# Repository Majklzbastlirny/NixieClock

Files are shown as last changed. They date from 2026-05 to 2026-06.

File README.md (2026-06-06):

# NixieClock (ESP-IDF firmware)

ESP-IDF + PlatformIO firmware for a 6-tube multiplexed nixie clock, replacing
the original ESPHome config (`nixieclock.yaml`, kept for reference). WiFi is used
for time sync and remote control; the clock keeps running (and keeps time, via
its RTC) with no network.

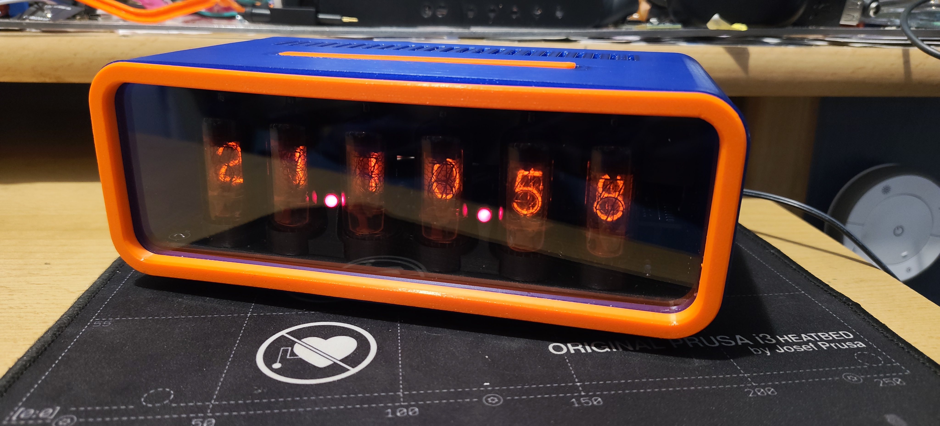
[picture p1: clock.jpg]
The clock


> **New here?** See **[GUIDE.md](GUIDE.md)** — a bilingual (English / Čeština)
> user guide with a *For everyone* section (setup, buttons, web page) and a
> *Power users* section (REST, MQTT/Home Assistant, building the firmware).

## Hardware

ESP32 (WROOM-32) on the **UCB32** controller board driving the
[**Unidisp**](https://github.com/Unipuls80/Unidisp) display board:

- Onboard UC3845 HV supply (~180 V, **no dimming input** → brightness is done in
  firmware by PWM-ing each tube's anode within its multiplex slot — the headline
  feature that wasn't possible under ESPHome).
- **MH74141** BCD cathode driver (old/slow Tesla part), **74×42** 1-of-10 anode
  multiplexer, 6× Z57xM/ZM1080 tubes. No per-digit decimal points — the only
  separator is the colon between the MM:SS pair.
- **PCF8563** RTC @ I²C 0x51 (driver also auto-detects DS1307/DS3231 @ 0x68).
- 5 front buttons on the multiplexed KEY line + a dedicated snooze button.
- Passive piezo buzzer on the ALM line (LEDC tone / RTTTL).
- Up to 2× **DS18B20** 1-Wire temperature sensors on GPIO13 (needs a 4.7 kΩ
  pull-up to 3.3 V).

Full pin map: [`components/common/include/pins.h`](components/common/include/pins.h).
Printable enclosure (case, bezel, panels, TPU feet) + print/assembly notes:
[`3D_Files/`](3D_Files/).

## Build & flash

Requires [PlatformIO](https://platformio.org/install) (CLI or the VS Code ext).

```sh
pio run                 # build
pio run -t upload       # build + flash over USB
pio device monitor      # serial console @ 115200
```

PlatformIO downloads the ESP-IDF 5.5 toolchain and the managed components
(`espressif/onewire_bus`, `espressif/ds18b20`) automatically on first build.
After changing a component's `idf_component.yml` or `REQUIRES`, do a clean
configure (`rm -rf .pio/build/esp32dev`) so the component manager re-runs.

> The board has **no auto-reset**: hold IO0, tap EN, release IO0 to enter
> download mode before `pio run -t upload`.

## First-time setup / credentials

Credentials live in NVS (set via the SoftAP portal or the web UI).
`components/common/include/secrets.h` (gitignored) is a **first-boot fallback
only**: once a WiFi SSID is stored in NVS the device trusts NVS exclusively (an
empty MQTT host means *no MQTT* — the client goes idle), and a factory reset
forces SoftAP setup on the next boot regardless of `secrets.h`.

To seed defaults at compile time, copy the template:

```sh
cp components/common/include/secrets.example.h components/common/include/secrets.h
# edit WIFI_SSID / WIFI_PASS / MQTT_* 
```

Or skip `secrets.h` entirely and provision over WiFi (see below).

## WiFi provisioning (SoftAP)

To set credentials without editing code (e.g. when lending the clock):

1. **Enter provisioning** — hold the provision button (button 5) during the
   boot window, or long-hold it (~3 s) during normal operation; it reboots into
   setup mode. (A board with no stored creds and no fallback SSID enters it
   automatically.)
2. The tubes show an **8-digit PIN** in two halves (colon lit = first half).
   Join the open-looking `NixieClock-XXXXXX` WiFi using that PIN as the WPA2
   password — so only someone looking at the clock can connect.
3. A captive portal opens: pick your network, enter the password (and optionally
   MQTT settings), save. The clock stores the creds and reboots onto your LAN.

WiFi/MQTT can also be changed live from the web UI's **Network** section (MQTT
applies immediately; WiFi on next reboot).

## Buttons

| Button | Short press | Long hold |
|---|---|---|
| 1 | Brightness up | — |
| 2 | Brightness down | — |
| 3 | Show temperature now | — |
| 4 | Anti-poison scrub now | — |
| 5 (provision) | Show IP address on tubes | ~3 s: provisioning · ~10 s: factory reset |
| Snooze | Snooze ringing alarm | Dismiss alarm (until tomorrow) |

Bonus combo: **hold brightness + and − together (~2 s)** toggles the alarm on/off.

## Control surfaces

All three share one settings store, so changes from any surface are reflected
everywhere instantly:

- **Web UI** — `http://<clock-ip>/` : brightness, night schedule, anti-poison,
  alarm (incl. day-of-week + melody + snooze), temperature slots/decimals, and
  network config. Tap button 5 to see the IP on the tubes.
- **MQTT + Home Assistant** — auto-discovers as a *Nixie Clock* device
  (`nixie-<mac>`). Topics under `nixieclock/<node>/…`, HA discovery under
  `homeassistant/…`.
- **REST/JSON** — `GET /api/state`, `POST /api/set?k=<key>` (value in body),
  `POST /api/action?a=<action>`, `GET /api/net`, `POST /api/netset`.

## Features

- Smooth multiplex PWM brightness, ghost-free (cathode-before-anode + dead-time).
- SNTP timekeeping (Europe/Prague), seeded from and written back to the RTC.
- Manual brightness + night dimming (default 20:30→06:00); hook for a future
  BH1750 light sensor.
- Anti-cathode-poisoning cycle (periodic + on-demand).
- Two temperature slots shown near the end of each minute (sec 52–55), each fed
  by MQTT or a DS18B20; configurable decimals; negatives shown by blinking
  (no minus glyph), colon used as the decimal point.
- Alarm with snooze + dismiss, day-of-week mask, and RTTTL melodies.
- Cold-start "slot machine" animation until the time is known.

## Project layout

```
platformio.ini             build config (env: esp32dev), custom partition table
partitions.csv             single ~2.8 MB app + NVS + SPIFFS (4 MB flash)
sdkconfig.defaults         ESP-IDF defaults
src/main.c                 app entry: orchestration + display draw loop
components/
  common/                  shared pin map + secrets (header-only)
  nixie/                   GPTimer multiplex display driver + PWM brightness
  i2cbus/                  shared I²C master + bus scanner
  rtcdev/                  RTC driver (PCF8563 / DS1307 / DS3231 auto-detect)
  netclock/                WiFi STA + SNTP
  netcfg/                  WiFi/MQTT credential store (NVS + secrets fallback)
  provision/               SoftAP captive-portal WiFi provisioning
  settings/                persisted settings blob (NVS) + change versioning
  control/                 shared key=value apply + state-JSON core
  mqttctrl/                MQTT client + Home Assistant autodiscovery
  webui/                   self-hosted web UI + REST/JSON API
  temps/                   temperature slots + DS18B20 (RMT 1-Wire)
  buttons/                 multiplexed-button debounce + classification
  alarm/                   alarm state machine
  buzzer/                  LEDC tone + RTTTL player
  antipoison/              anti-cathode-poisoning routine
```

Architecture note: `control` is the single place that maps a setting key=value
and renders the state JSON; MQTT, the web UI, and REST all go through it, so
adding a setting touches one switch and one JSON builder, not three.

## License

This project uses reciprocal ("share-alike") open licenses — you may use, copy,
and modify it, including commercially, but you must publish your modifications to
whichever part you change:

- **Firmware / source code** — [GNU GPL v3](LICENSE) (`LICENSE` at the repo root).
- **UCB32 controller board** (`PCB_Sources/ucb vibecheck_final/`) —
  [CERN-OHL-S v2](PCB_Sources/ucb%20vibecheck_final/LICENSE.txt) (CERN Open
  Hardware Licence, Strongly Reciprocal).

Third-party content keeps its own license: the **Unidisp** display board
(`PCB_Sources/Unidisp-main/`) is licensed by its author under CERN-OHL-W (Weakly
Reciprocal) — see its bundled `LICENSE`. The original ESPHome reference
(`nixieclock.yaml`) is retained only for reference.

## Credits

This started as a university project. The **Unidisp** digitron display board —
the HV supply, multiplexing, and tube driving — is the work of
[**@Unipuls80**](https://github.com/Unipuls80), along with his original
[Unidisp](https://github.com/Unipuls80/Unidisp) and an
[MH106 ASIC-based controller (ucb106)](https://github.com/Unipuls80/ucb106).

The **UCB32** controller board and this ESP32 firmware are my "modern" take on
driving the same display — by **Michal Basler** ([@Majklzbastlirny](https://github.com/Majklzbastlirny)).

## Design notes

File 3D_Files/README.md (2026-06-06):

# 3D-printed enclosure

Printable parts for the clock case. All files are `.3mf`. Print the rigid parts
in **PETG** (chosen mainly because the 7805 regulator runs hot, and PETG handles
the heat better than PLA); print the feet in **TPU**.

| Preview | Part | File | Qty | Supports | Notes |
|---|---|---|-----|---|---|
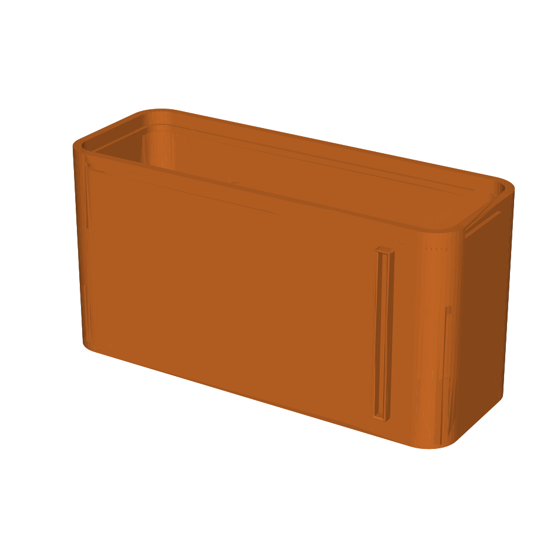
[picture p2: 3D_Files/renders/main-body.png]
|  | Main body / shell | [`main-body.3mf`](main-body.3mf) | 1 | **Yes** | The enclosure everything mounts inside. Takes 2× M3 heat-set inserts (see *Hardware*). |
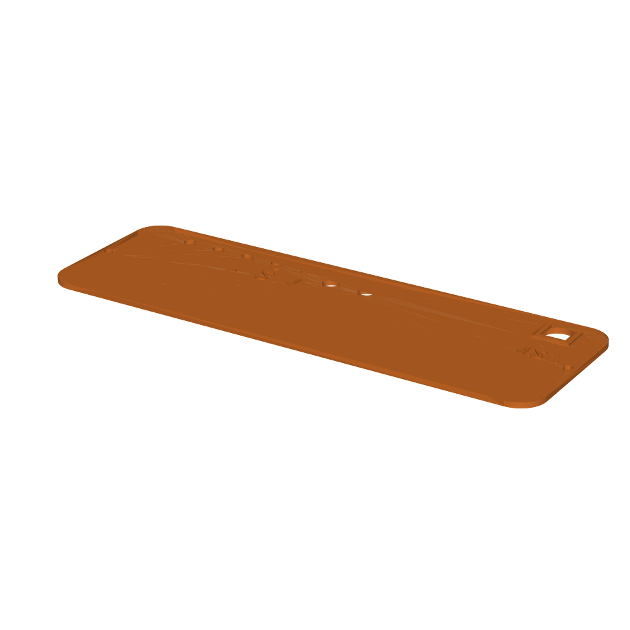
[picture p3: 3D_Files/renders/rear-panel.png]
|  | Rear panel | [`rear-panel.3mf`](rear-panel.3mf) | 1 | No | MMU / multi-color: printed labels for each rear button, the temperature-probe jacks, and the barrel-jack voltage. Screws onto the main body. |
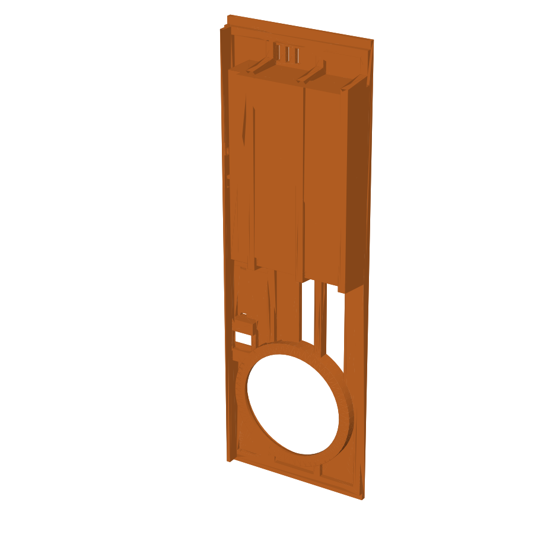
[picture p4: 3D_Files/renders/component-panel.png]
|  | Component panel | [`component-panel.3mf`](component-panel.3mf) | 1 | **Yes** | Internal bracket that holds the accessory hardware: alarm speaker, RTC coin-cell holder, and the snooze button. |
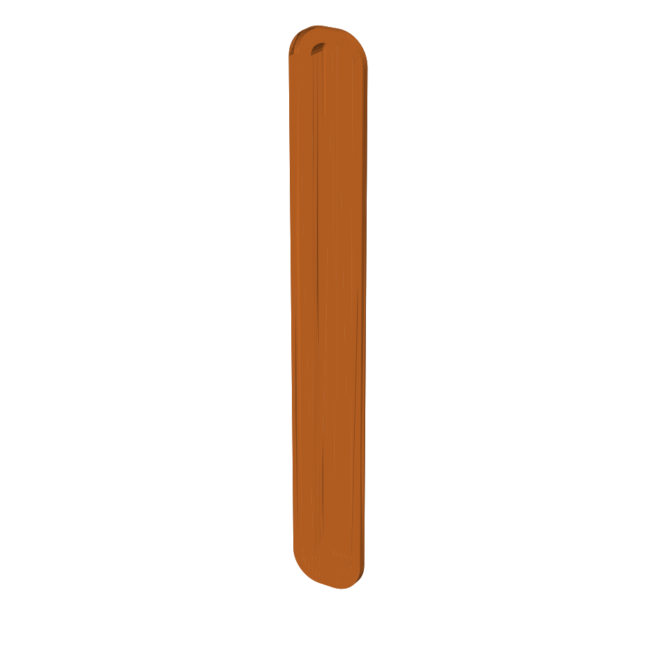
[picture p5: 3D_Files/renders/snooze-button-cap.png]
|  | Snooze button cap | [`snooze-button-cap.3mf`](snooze-button-cap.3mf) | 1 | No | One printed rocker cap; the two physical tact switches sit under its edges. Mounts in the component panel. |
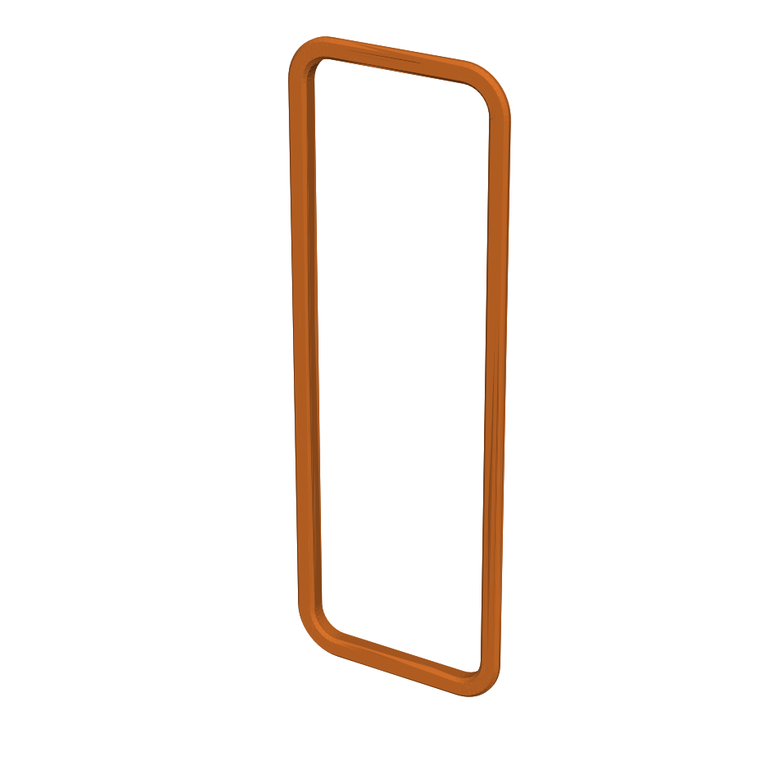
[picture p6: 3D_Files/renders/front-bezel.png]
|  | Front bezel | [`front-bezel.3mf`](front-bezel.3mf) | 1 | No | Hides the rough-cut front plexiglass edge. **Scale to 98 %** to fit as-is — or shave the lip if you print at 100 %. |
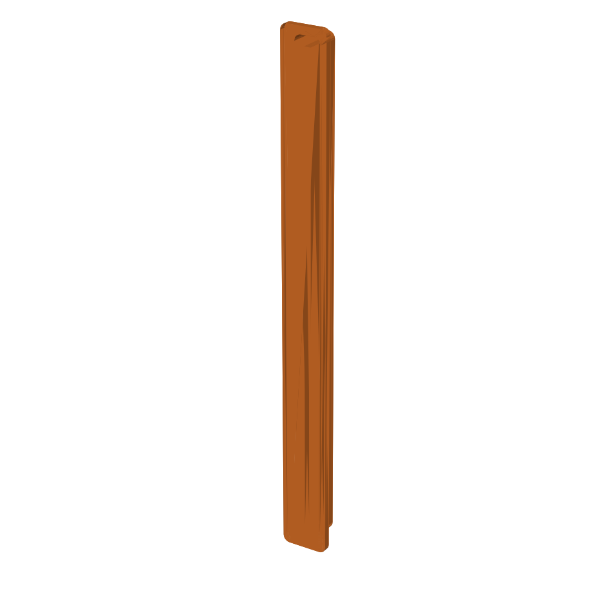
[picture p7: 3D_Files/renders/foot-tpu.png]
|  | Foot | [`foot-tpu.3mf`](foot-tpu.3mf) | 2 | No | Print in **TPU** (flexible). |

> Preview images in `renders/` are auto-generated from the `.3mf` files by
> [`_render.py`](_render.py) (a throwaway matplotlib/trimesh helper).

## Hardware (case assembly)

- **2× M3 heat-set threaded inserts** — installed in the main body.
- **2× M3×4 screws** — fasten the rear panel into those inserts.

(Electronics/wiring hardware is covered in the main project docs.)

## Print tips

- Everything rigid is **PETG** — the 7805 linear regulator dumps a fair bit of
  heat, so PLA isn't ideal near it.
- The main body and component panel use supports; orient so the support contact
  stays off visible faces.
- The rear panel is set up for a multi-material (MMU) printer so the labels come
  out in a contrasting color; on a single-material printer it still prints fine,
  the markings just won't be color-separated.
- Front bezel: if it's tight, the 98 % scale is the easy fix; the alternative is
  trimming the locating lip.

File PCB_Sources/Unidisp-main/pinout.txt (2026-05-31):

P.V.B. @ Crazy Electronics   13/02/23

------X1------
		
		Konektor pro připojení napájení. (+) je připojeno ke středovému trnu.

------X2------

S0/LSB		Paralelní vstup multiplexování. Hodnotě 0 odpovídá digitron úplně vpravo,
S1		hodnotě 5 odpovídá digitron úplně vlevo, hodnoty 6 a výše zhasínají displej
S2/MSB

D0/LSB		Paralelní vstup zobrazené číslice, formát BCD
D1
D2
D3/MSB

------X3------

KEY		Výstup tlačítek. Tlačítka jsou multiplexovaná, aktivní úroveň L posutá o jeden úbytek diody na 0,6V. 
		Tlačítka jsou multiplexovaná společně s digitrony: 
		S1:LLH, S2:HHL, S3:LHL, S4:HLL, S5:LLL (S0, S1, S2)

ALM:		Ovládání budiče pro akustický měnič budíku. 

DP:		Řízení desetinných teček. Úroveň H otevírá tranzistor, spínající katodu navolenou pájecími
		body JP1, JP2. Tečky jsou rovněž multiplexované.

COL:		Řízení spínače oddělovačů. Oddělovači se rozumí dvojtečky mezi páry digitronů - 12:34:56.

P5V:		Rozvod 5V pro napájení nadřazených obvodů. Bez přídavného chladiče na A1 doporučuji odebírat max 200mA.

GND:		Rozvod nuly. (GND)

P12V:		Rozvod nestabilizovaného napájení. Napětí odpovídá napětí dodávaného z externího napáječe přes X1.

-----X4,5-----

		Připojení LED diod oddělovačů. Oddělovače jsou tvořeny dvěma LED připojenými ke konektorům X4, X5. 
		Anody jsou spojené do vývodu 2, katody na vývodech 1, 3 X4, respektive X5.

-----X6,7-----

		Připojení akustického měniče, budič je navržen především pro buzení pasivního piezo měniče.
		Umožňuje i buzení reproduktorku přes vazební kondenzátor. Výstup je na X6, X7 je 0V.

Všechny log. I/O jsou úrovní TTL 5V.

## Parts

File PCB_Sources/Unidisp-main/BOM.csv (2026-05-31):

Indukčnosti
L1 | 100uH 2A pp. 50kHz | radiální
Rezistory
R1 | CdS 5mm | -
R2, R45 | 47k 5% | R0207
R3 | 150k 5% | R0207
R4 | 10k 1% | R0207
R5, R47 | 47R 5% | R0207
R6 | 2k2 5% | R0207
R7, R8 | 2R2 5% | R0207
R9 | 390k 1% | R0207
R10 | 100k 1% | R0207
R11 | 6k8 1% | R0207
R12 .. R23 | 22k 5% | R0207
R30 .. R35
R24 .. R29 | 330k 5% | R0207
R36 | 1k 5% | R0207
R37, R38 | 10k 5% | R0207
R43, R44
R39 .. R42, R46 | 560R 5% | R0207
Kondenzátory
C1 | 470uF 16V | elektrol. radiální
C2, C3, C9 | 100n 16V | keramický
C10, C11
C4 | 100p 16V | keramický
C5 | 10n 16V | keramický
C6 | 1n5 16V | keramický
C7 | 2n2 16V | keramický
C8 | 4,7uF 250V | elektrol. radiální
Diody
V1 | 1N4007 | -
V2 | UF4007 | -
V3..V7 | 1N4148 | -
Tranzistory
VT1 | IRF740 | upevnit k DPS
VT2..VT7 | MPSA92 | -
VT8..VT13, VT15 | MPSA42 | -
VT14, VT16 | BC547 | -
VT17 | BC556 | -
Integrované obvody
A1 | MA7805 | upevnit k DPS
A2 | UC3845 | -
D1 | 74x42 | -
D2 | 74x141 | -
Výbojky
E1..E6 | Z57xM, ZM1080(T) a ekvivalentní
Konektory
X1 | zdířka souosá | 5,5mm/2,1mm
X2..X7 | hřeben, samec | 2,54mm
Pojistky
F1 | podle celk. odběru | 5x20mm
pouzdro pro F1 | PTF76 | 15mm rozteč

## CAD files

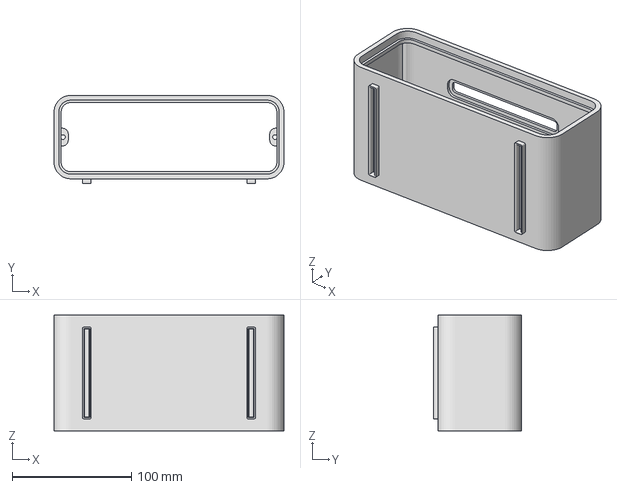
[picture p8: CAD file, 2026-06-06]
3D_Files/main-body.3mf
193.0 x 74.0 x 97.0 mm

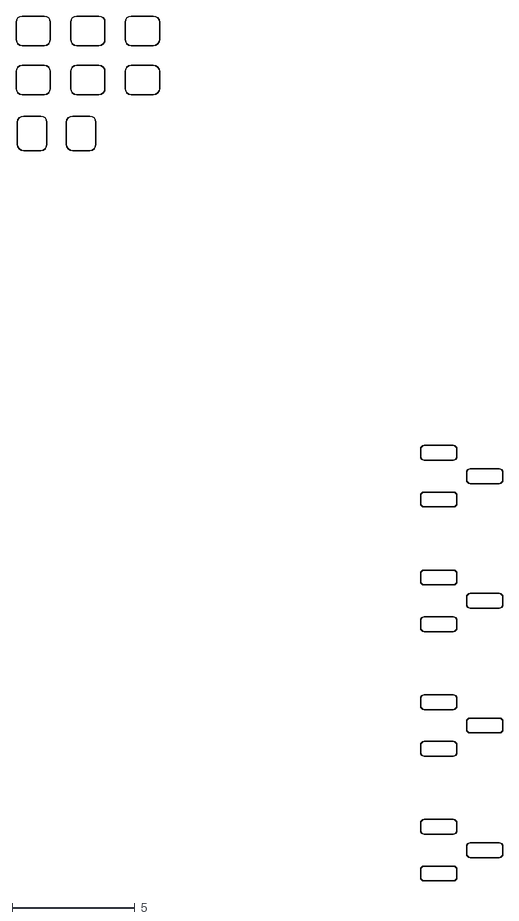
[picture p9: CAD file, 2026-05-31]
PCB_Sources/ucb vibecheck_final/UCB32-PasteBottom.dxf
19.8 x 35.2

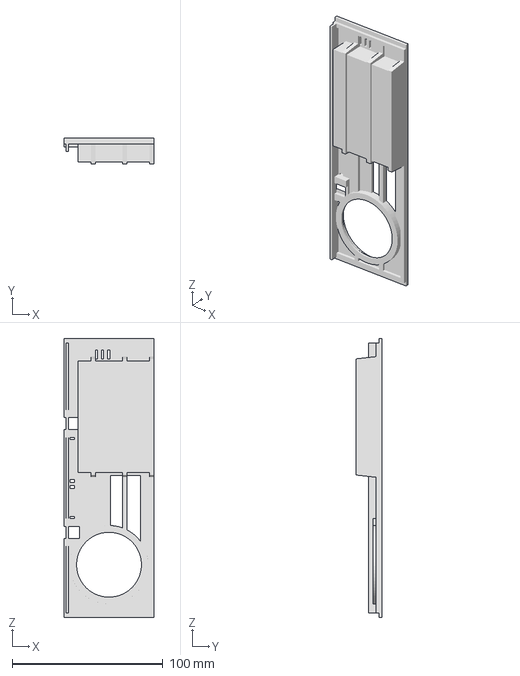
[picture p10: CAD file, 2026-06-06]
3D_Files/component-panel.3mf
60.0 x 17.5 x 185.0 mm

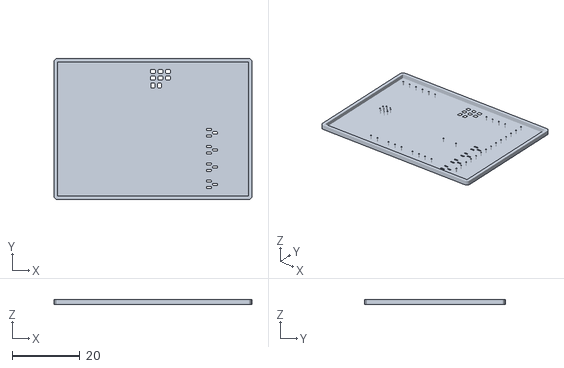
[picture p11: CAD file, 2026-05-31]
PCB_Sources/ucb vibecheck_final/bottomStencil.stl
58.5 x 41.7 x 1.45

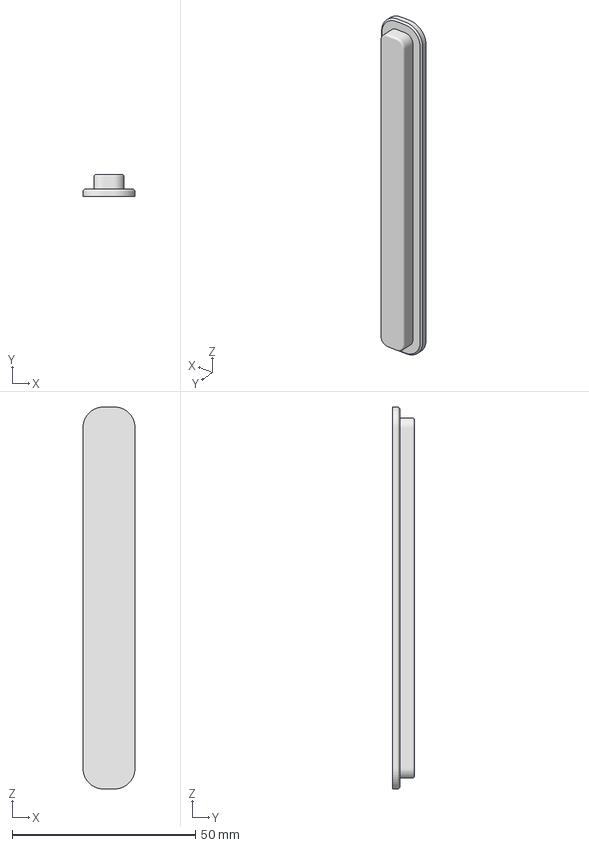
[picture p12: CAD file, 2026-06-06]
3D_Files/snooze-button-cap.3mf
14.2 x 6.00 x 104.2 mm

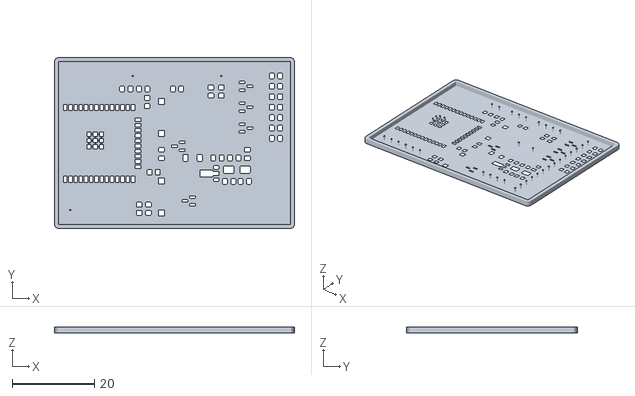
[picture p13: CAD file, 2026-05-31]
PCB_Sources/ucb vibecheck_final/topStencil.stl
58.5 x 41.7 x 1.45

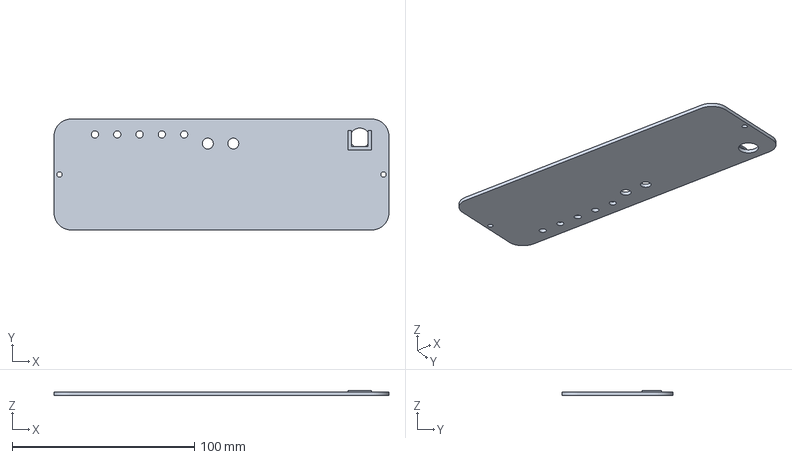
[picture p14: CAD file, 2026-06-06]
3D_Files/rear-panel.3mf
184.0 x 61.0 x 3.00 mm

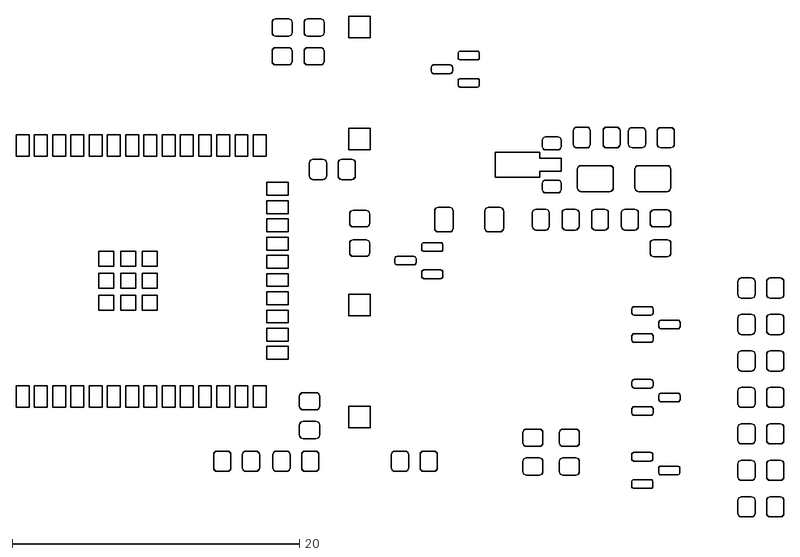
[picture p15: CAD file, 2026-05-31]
PCB_Sources/ucb vibecheck_final/UCB32-PasteTop.dxf
53.5 x 34.9

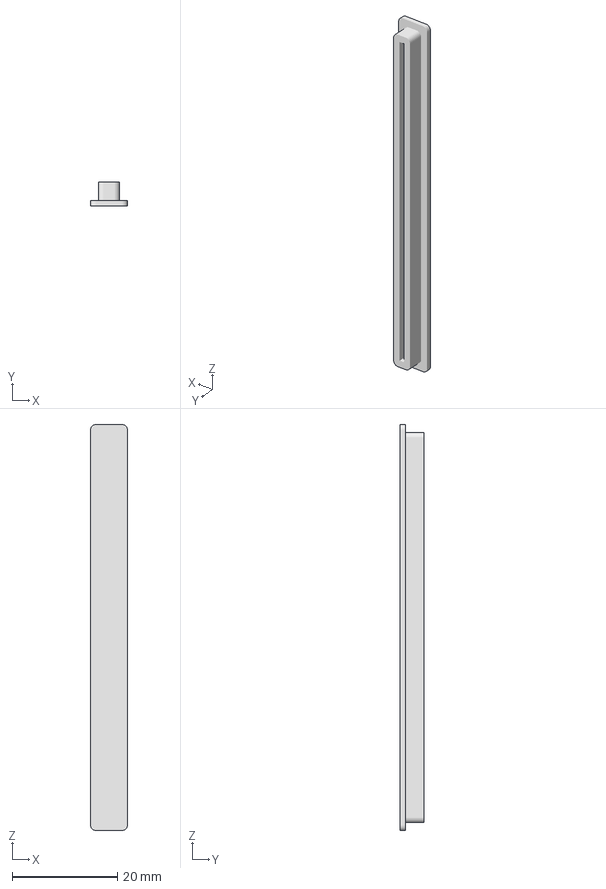
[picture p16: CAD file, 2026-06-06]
3D_Files/foot-tpu.3mf
7.00 x 4.50 x 77.0 mm

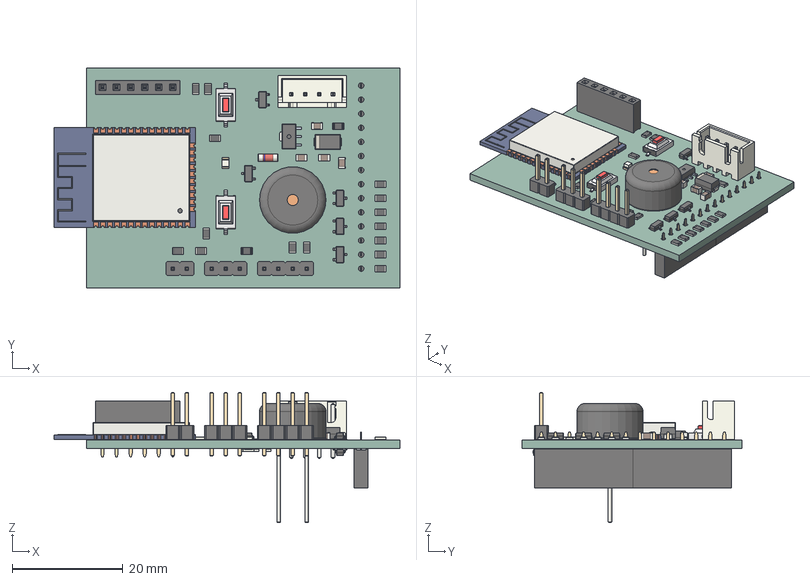
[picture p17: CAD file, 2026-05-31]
PCB_Sources/ucb vibecheck_final/UCB32.step
62.4 x 39.7 x 23.5 mm
R_0805_2012Metric x 21
JST_B4B_XH_A
C_0805_2012Metric x 4
PinSocket_1x06_P254mm_Vertical
SW_SPST_CK_RS282G05A3 x 2
D_SMA
ESP32-WROOM-32
CQ assembly
SOT_23 x 9
PinHeader_1x04_P254mm_Vertical
PinHeader_1x02_P254mm_Vertical
D_MiniMELF_Standard
Buzzer_TDK_PS1240P02BT_D122mm_H65mm
PinHeader_1x03_P254mm_Vertical
LED_0805_2012Metric
PinSocket_1x07_P254mm_Vertical x 2
UCB32_PCB

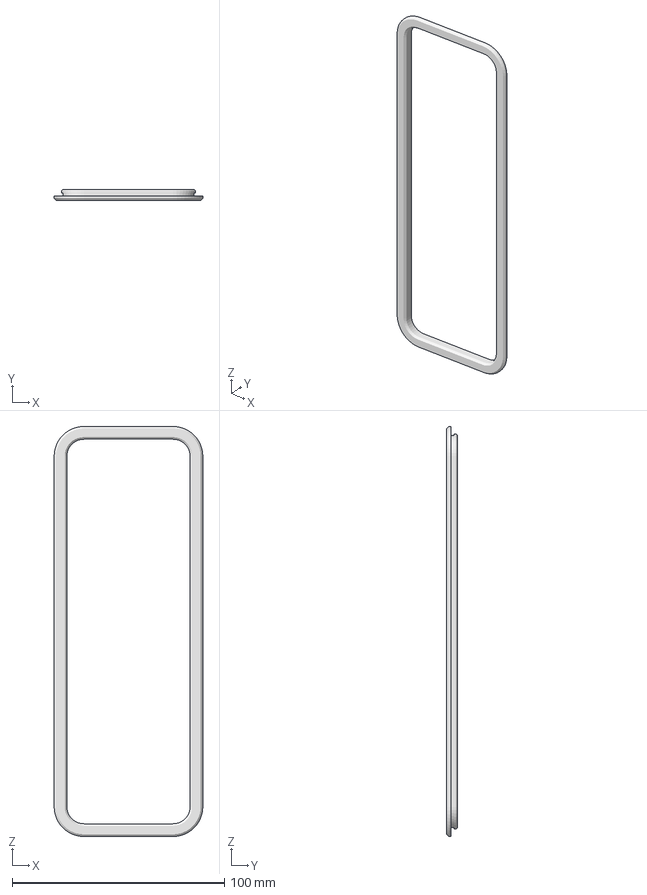
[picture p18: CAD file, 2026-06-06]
3D_Files/front-bezel.3mf
70.0 x 5.00 x 193.0 mm

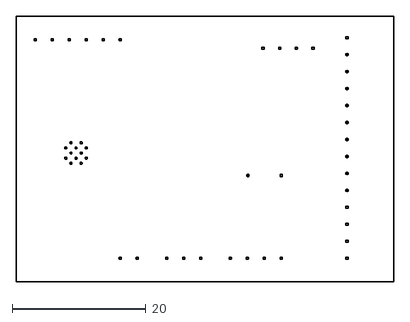
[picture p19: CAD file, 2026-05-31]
PCB_Sources/ucb vibecheck_final/UCB32-EdgeCuts.dxf
56.5 x 39.7

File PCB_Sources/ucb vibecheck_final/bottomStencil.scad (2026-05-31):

// Generated by SolidPython 1.1.3 on 2024-10-30 19:15:28
$fa = 0.4; $fs = 0.4;


rotate(a = 0, v = [1, 0, 0]) {
	difference() {
		scale(v = [1, 1, 1]) {
			difference() {
				linear_extrude(height = 1.4500000000) {
					offset(r = 1.0000000000) {
						import(file = "C:/Users/Michal/Downloads/ucb vibecheck_final/ucb vibecheck_final/UCB32-EdgeCuts.dxf", origin = [0, 0]);
					}
				}
				translate(v = [0, 0, 0.1500000000]) {
					linear_extrude(height = 1.4500000000) {
						translate(v = [0, 0, 0]) {
							import(file = "C:/Users/Michal/Downloads/ucb vibecheck_final/ucb vibecheck_final/UCB32-EdgeCuts.dxf", origin = [0, 0]);
						}
					}
				}
			}
		}
		linear_extrude(center = true, height = 0.6000000000) {
			translate(v = [0, 0, 0]) {
				import(file = "C:/Users/Michal/Downloads/ucb vibecheck_final/ucb vibecheck_final/UCB32-PasteBottom.dxf", origin = [0, 0]);
			}
		}
	}
}
/***********************************************
*********      SolidPython code:      **********
************************************************
 
from pcbnewTransition import pcbnew
import numpy as np
import json
from collections import OrderedDict
from kikit.common import *
from kikit.defs import *
from kikit.substrate import Substrate, extractRings, toShapely, linestringToKicad
from kikit.export import gerberImpl, pasteDxfExport
from kikit.export import exportSettingsJlcpcb
import solid
import solid.utils
import subprocess
import shutil
from kikit.common import removeComponents, parseReferences

from shapely.geometry import Point


OUTER_BORDER = fromMm(7.5)
INNER_BORDER = fromMm(5)
MOUNTING_HOLES_COUNT = 3
MOUNTING_HOLE_R = fromMm(1)
HOLE_SPACING = fromMm(20)

def addBottomCounterpart(board, item):
    item = item.Duplicate()
    item.SetLayer(Layer.B_Paste)
    board.Add(item)

def addRoundedCorner(board, center, start, end, thickness):
    corner = pcbnew.PCB_SHAPE()
    corner.SetShape(STROKE_T.S_ARC)
    corner.SetCenter(toKiCADPoint((center[0], center[1])))
    corner.SetStart(toKiCADPoint((start[0], start[1])))

    if np.cross(start - center, end - center) > 0:
        corner.SetArcAngleAndEnd(fromDegrees(90), True)
    else:
        corner.SetArcAngleAndEnd(fromDegrees(-90), True)
    corner.SetWidth(thickness)
    corner.SetLayer(Layer.F_Paste)
    board.Add(corner)
    addBottomCounterpart(board, corner)

def addLine(board, start, end, thickness):
    line = pcbnew.PCB_SHAPE()
    line.SetShape(STROKE_T.S_SEGMENT)
    line.SetStart(toKiCADPoint((start[0], start[1])))
    line.SetEnd(toKiCADPoint((end[0], end[1])))
    line.SetWidth(thickness)
    line.SetLayer(Layer.F_Paste)
    board.Add(line)
    addBottomCounterpart(board, line)

def addBite(board, origin, direction, normal, thickness):
    """
    Adds a bite to the stencil, direction points to the bridge, normal points
    inside the stencil
    """
    direction = normalize(direction) * thickness
    normal = normalize(normal) * thickness
    center = toKiCADPoint((origin[0], origin[1])) + toKiCADPoint((normal[0], normal[1]))
    start = origin
    end = center + toKiCADPoint((direction[0], direction[1]))
    # addLine(board, end, end + normal / 2, thickness)
    addRoundedCorner(board, center, start, end, thickness)

def numberOfCuts(length, bridgeWidth, bridgeSpacing):
    """
    Return number of bridges which fit inside the length and cut length
    """
    count = int(np.floor((length + bridgeWidth) / (bridgeWidth + bridgeSpacing)))
    cutLength = (length - (count - 1) * bridgeWidth) / count
    return count, cutLength

def addFrame(board, rect, bridgeWidth, bridgeSpacing, clearance):
    """
    Add rectangular frame to the board
    """
    R=fromMm(1)

    corners = [
        (tl(rect), toKiCADPoint((R, 0)), toKiCADPoint((0, R))), # TL
        (tr(rect), toKiCADPoint((0, R)), toKiCADPoint((-R, 0))), # TR
        (br(rect), toKiCADPoint((-R, 0)), toKiCADPoint((0, -R))), # BR
        (bl(rect), toKiCADPoint((0, -R)), toKiCADPoint((R, 0))) # BL
    ]
    for c, sOffset, eOffset in corners:
        addRoundedCorner(board, c + sOffset + eOffset, c + sOffset, c + eOffset, clearance)

    count, cutLength = numberOfCuts(rect.GetWidth() - 2 * R, bridgeWidth, bridgeSpacing)
    for i in range(count):
        start = rect.GetX() + R + i * bridgeWidth + i * cutLength
        end = start + cutLength

        y1, y2 = rect.GetY(), rect.GetY() + rect.GetHeight()
        addLine(board, toKiCADPoint((start, y1)), toKiCADPoint((end, y1)), clearance)
        if i != 0:
            addBite(board, toKiCADPoint((start, y1)), toKiCADPoint((-1, 0)), toKiCADPoint((0, 1)), clearance)
        if i != count - 1:
            addBite(board, toKiCADPoint((end, y1)), toKiCADPoint((1, 0)), toKiCADPoint((0, 1)), clearance)
        addLine(board, toKiCADPoint((start, y2)), toKiCADPoint((end, y2)), clearance)
        if i != 0:
            addBite(board, toKiCADPoint((start, y2)), toKiCADPoint((-1, 0)), toKiCADPoint((0, -1)), clearance)
        if i != count - 1:
            addBite(board, toKiCADPoint((end, y2)), toKiCADPoint((1, 0)), toKiCADPoint((0, -1)), clearance)

    count, cutLength = numberOfCuts(rect.GetHeight() - 2 * R, bridgeWidth, bridgeSpacing)
    for i in range(count):
        start = rect.GetY() + R + i * bridgeWidth + i * cutLength
        end = start + cutLength

        x1, x2 = rect.GetX(), rect.GetX() + rect.GetWidth()
        addLine(board, toKiCADPoint((x1, start)), toKiCADPoint((x1, end)), clearance)
        if i != 0:
            addBite(board, toKiCADPoint((x1, start)), toKiCADPoint((0, -1)), toKiCADPoint((1, 0)), clearance)
        if i != count - 1:
            addBite(board, toKiCADPoint((x1, end)), toKiCADPoint((0, 1)), toKiCADPoint((1, 0)), clearance)
        addLine(board, toKiCADPoint((x2, start)), toKiCADPoint((x2, end)), clearance)
        if i != 0:
            addBite(board, toKiCADPoint((x2, start)), toKiCADPoint((0, -1)), toKiCADPoint((-1, 0)), clearance)
        if i != count - 1:
            addBite(board, toKiCADPoint((x2, end)), toKiCADPoint((0, 1)), toKiCADPoint((-1, 0)), clearance)

def addHole(board, position, radius):
    circle = pcbnew.PCB_SHAPE()
    circle.SetShape(STROKE_T.S_CIRCLE)
    circle.SetCenter(toKiCADPoint((position[0], position[1])))
    # Set 3'oclock point of the circle to set radius
    circle.SetEnd(toKiCADPoint((position[0], position[1])) + toKiCADPoint((radius/2, 0)))

    circle.SetWidth(radius)
    circle.SetLayer(Layer.F_Paste)
    board.Add(circle)
    addBottomCounterpart(board, circle)

def addJigFrame(board, jigFrameSize, bridgeWidth=fromMm(2),
                bridgeSpacing=fromMm(10), clearance=fromMm(0.5)):
    """
    Given a Pcbnew board finds the board outline and creates a stencil for
    KiKit's stencil jig.

    Mainly, adds mounting holes and mouse bites to define the panel outline.

    jigFrameSize is a tuple (width, height).
    """
    bBox = findBoardBoundingBox(board)
    frameSize = rectByCenter(rectCenter(bBox),
        jigFrameSize[0] + 2 * (OUTER_BORDER + INNER_BORDER),
        jigFrameSize[1] + 2 * (OUTER_BORDER + INNER_BORDER))
    cutSize = rectByCenter(rectCenter(bBox),
        jigFrameSize[0] + 2 * (OUTER_BORDER + INNER_BORDER) - fromMm(1),
        jigFrameSize[1] + 2 * (OUTER_BORDER + INNER_BORDER) - fromMm(1))
    addFrame(board, cutSize, bridgeWidth, bridgeSpacing, clearance)

    for i in range(MOUNTING_HOLES_COUNT):
        x = frameSize.GetX() + OUTER_BORDER / 2 + (i + 1) * (frameSize.GetWidth() - OUTER_BORDER) / (MOUNTING_HOLES_COUNT + 1)
        addHole(board, toKiCADPoint((x, OUTER_BORDER / 2 + frameSize.GetY())), MOUNTING_HOLE_R)
        addHole(board, toKiCADPoint((x, - OUTER_BORDER / 2 +frameSize.GetY() + frameSize.GetHeight())), MOUNTING_HOLE_R)
    for i in range(MOUNTING_HOLES_COUNT):
        y = frameSize.GetY() + OUTER_BORDER / 2 + (i + 1) * (frameSize.GetHeight() - OUTER_BORDER) / (MOUNTING_HOLES_COUNT + 1)
        addHole(board, toKiCADPoint((OUTER_BORDER / 2 + frameSize.GetX(), y)), MOUNTING_HOLE_R)
        addHole(board, toKiCADPoint((- OUTER_BORDER / 2 +frameSize.GetX() + frameSize.GetWidth(), y)), MOUNTING_HOLE_R)

    PIN_TOLERANCE = fromMm(0.05)
    addHole(board, tl(frameSize) + toKiCADPoint((OUTER_BORDER / 2, OUTER_BORDER / 2)), MOUNTING_HOLE_R + PIN_TOLERANCE)
    addHole(board, tr(frameSize) + toKiCADPoint((-OUTER_BORDER / 2, OUTER_BORDER / 2)), MOUNTING_HOLE_R + PIN_TOLERANCE)
    addHole(board, br(frameSize) + toKiCADPoint((-OUTER_BORDER / 2, -OUTER_BORDER / 2)), MOUNTING_HOLE_R + PIN_TOLERANCE)
    addHole(board, bl(frameSize) + toKiCADPoint((OUTER_BORDER / 2, -OUTER_BORDER / 2)), MOUNTING_HOLE_R + PIN_TOLERANCE)
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

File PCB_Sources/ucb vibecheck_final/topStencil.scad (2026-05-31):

// Generated by SolidPython 1.1.3 on 2024-10-30 19:15:31
$fa = 0.4; $fs = 0.4;


rotate(a = 180, v = [1, 0, 0]) {
	difference() {
		scale(v = [1, 1, -1]) {
			difference() {
				linear_extrude(height = 1.4500000000) {
					offset(r = 1.0000000000) {
						import(file = "C:/Users/Michal/Downloads/ucb vibecheck_final/ucb vibecheck_final/UCB32-EdgeCuts.dxf", origin = [0, 0]);
					}
				}
				translate(v = [0, 0, 0.1500000000]) {
					linear_extrude(height = 1.4500000000) {
						translate(v = [0, 0, 0]) {
							import(file = "C:/Users/Michal/Downloads/ucb vibecheck_final/ucb vibecheck_final/UCB32-EdgeCuts.dxf", origin = [0, 0]);
						}
					}
				}
			}
		}
		linear_extrude(center = true, height = 0.6000000000) {
			translate(v = [0, 0, 0]) {
				import(file = "C:/Users/Michal/Downloads/ucb vibecheck_final/ucb vibecheck_final/UCB32-PasteTop.dxf", origin = [0, 0]);
			}
		}
	}
}
/***********************************************
*********      SolidPython code:      **********
************************************************
 
from pcbnewTransition import pcbnew
import numpy as np
import json
from collections import OrderedDict
from kikit.common import *
from kikit.defs import *
from kikit.substrate import Substrate, extractRings, toShapely, linestringToKicad
from kikit.export import gerberImpl, pasteDxfExport
from kikit.export import exportSettingsJlcpcb
import solid
import solid.utils
import subprocess
import shutil
from kikit.common import removeComponents, parseReferences

from shapely.geometry import Point


OUTER_BORDER = fromMm(7.5)
INNER_BORDER = fromMm(5)
MOUNTING_HOLES_COUNT = 3
MOUNTING_HOLE_R = fromMm(1)
HOLE_SPACING = fromMm(20)

def addBottomCounterpart(board, item):
    item = item.Duplicate()
    item.SetLayer(Layer.B_Paste)
    board.Add(item)

def addRoundedCorner(board, center, start, end, thickness):
    corner = pcbnew.PCB_SHAPE()
    corner.SetShape(STROKE_T.S_ARC)
    corner.SetCenter(toKiCADPoint((center[0], center[1])))
    corner.SetStart(toKiCADPoint((start[0], start[1])))

    if np.cross(start - center, end - center) > 0:
        corner.SetArcAngleAndEnd(fromDegrees(90), True)
    else:
        corner.SetArcAngleAndEnd(fromDegrees(-90), True)
    corner.SetWidth(thickness)
    corner.SetLayer(Layer.F_Paste)
    board.Add(corner)
    addBottomCounterpart(board, corner)

def addLine(board, start, end, thickness):
    line = pcbnew.PCB_SHAPE()
    line.SetShape(STROKE_T.S_SEGMENT)
    line.SetStart(toKiCADPoint((start[0], start[1])))
    line.SetEnd(toKiCADPoint((end[0], end[1])))
    line.SetWidth(thickness)
    line.SetLayer(Layer.F_Paste)
    board.Add(line)
    addBottomCounterpart(board, line)

def addBite(board, origin, direction, normal, thickness):
    """
    Adds a bite to the stencil, direction points to the bridge, normal points
    inside the stencil
    """
    direction = normalize(direction) * thickness
    normal = normalize(normal) * thickness
    center = toKiCADPoint((origin[0], origin[1])) + toKiCADPoint((normal[0], normal[1]))
    start = origin
    end = center + toKiCADPoint((direction[0], direction[1]))
    # addLine(board, end, end + normal / 2, thickness)
    addRoundedCorner(board, center, start, end, thickness)

def numberOfCuts(length, bridgeWidth, bridgeSpacing):
    """
    Return number of bridges which fit inside the length and cut length
    """
    count = int(np.floor((length + bridgeWidth) / (bridgeWidth + bridgeSpacing)))
    cutLength = (length - (count - 1) * bridgeWidth) / count
    return count, cutLength

def addFrame(board, rect, bridgeWidth, bridgeSpacing, clearance):
    """
    Add rectangular frame to the board
    """
    R=fromMm(1)

    corners = [
        (tl(rect), toKiCADPoint((R, 0)), toKiCADPoint((0, R))), # TL
        (tr(rect), toKiCADPoint((0, R)), toKiCADPoint((-R, 0))), # TR
        (br(rect), toKiCADPoint((-R, 0)), toKiCADPoint((0, -R))), # BR
        (bl(rect), toKiCADPoint((0, -R)), toKiCADPoint((R, 0))) # BL
    ]
    for c, sOffset, eOffset in corners:
        addRoundedCorner(board, c + sOffset + eOffset, c + sOffset, c + eOffset, clearance)

    count, cutLength = numberOfCuts(rect.GetWidth() - 2 * R, bridgeWidth, bridgeSpacing)
    for i in range(count):
        start = rect.GetX() + R + i * bridgeWidth + i * cutLength
        end = start + cutLength

        y1, y2 = rect.GetY(), rect.GetY() + rect.GetHeight()
        addLine(board, toKiCADPoint((start, y1)), toKiCADPoint((end, y1)), clearance)
        if i != 0:
            addBite(board, toKiCADPoint((start, y1)), toKiCADPoint((-1, 0)), toKiCADPoint((0, 1)), clearance)
        if i != count - 1:
            addBite(board, toKiCADPoint((end, y1)), toKiCADPoint((1, 0)), toKiCADPoint((0, 1)), clearance)
        addLine(board, toKiCADPoint((start, y2)), toKiCADPoint((end, y2)), clearance)
        if i != 0:
            addBite(board, toKiCADPoint((start, y2)), toKiCADPoint((-1, 0)), toKiCADPoint((0, -1)), clearance)
        if i != count - 1:
            addBite(board, toKiCADPoint((end, y2)), toKiCADPoint((1, 0)), toKiCADPoint((0, -1)), clearance)

    count, cutLength = numberOfCuts(rect.GetHeight() - 2 * R, bridgeWidth, bridgeSpacing)
    for i in range(count):
        start = rect.GetY() + R + i * bridgeWidth + i * cutLength
        end = start + cutLength

        x1, x2 = rect.GetX(), rect.GetX() + rect.GetWidth()
        addLine(board, toKiCADPoint((x1, start)), toKiCADPoint((x1, end)), clearance)
        if i != 0:
            addBite(board, toKiCADPoint((x1, start)), toKiCADPoint((0, -1)), toKiCADPoint((1, 0)), clearance)
        if i != count - 1:
            addBite(board, toKiCADPoint((x1, end)), toKiCADPoint((0, 1)), toKiCADPoint((1, 0)), clearance)
        addLine(board, toKiCADPoint((x2, start)), toKiCADPoint((x2, end)), clearance)
        if i != 0:
            addBite(board, toKiCADPoint((x2, start)), toKiCADPoint((0, -1)), toKiCADPoint((-1, 0)), clearance)
        if i != count - 1:
            addBite(board, toKiCADPoint((x2, end)), toKiCADPoint((0, 1)), toKiCADPoint((-1, 0)), clearance)

def addHole(board, position, radius):
    circle = pcbnew.PCB_SHAPE()
    circle.SetShape(STROKE_T.S_CIRCLE)
    circle.SetCenter(toKiCADPoint((position[0], position[1])))
    # Set 3'oclock point of the circle to set radius
    circle.SetEnd(toKiCADPoint((position[0], position[1])) + toKiCADPoint((radius/2, 0)))

    circle.SetWidth(radius)
    circle.SetLayer(Layer.F_Paste)
    board.Add(circle)
    addBottomCounterpart(board, circle)

def addJigFrame(board, jigFrameSize, bridgeWidth=fromMm(2),
                bridgeSpacing=fromMm(10), clearance=fromMm(0.5)):
    """
    Given a Pcbnew board finds the board outline and creates a stencil for
    KiKit's stencil jig.

    Mainly, adds mounting holes and mouse bites to define the panel outline.

    jigFrameSize is a tuple (width, height).
    """
    bBox = findBoardBoundingBox(board)
    frameSize = rectByCenter(rectCenter(bBox),
        jigFrameSize[0] + 2 * (OUTER_BORDER + INNER_BORDER),
        jigFrameSize[1] + 2 * (OUTER_BORDER + INNER_BORDER))
    cutSize = rectByCenter(rectCenter(bBox),
        jigFrameSize[0] + 2 * (OUTER_BORDER + INNER_BORDER) - fromMm(1),
        jigFrameSize[1] + 2 * (OUTER_BORDER + INNER_BORDER) - fromMm(1))
    addFrame(board, cutSize, bridgeWidth, bridgeSpacing, clearance)

    for i in range(MOUNTING_HOLES_COUNT):
        x = frameSize.GetX() + OUTER_BORDER / 2 + (i + 1) * (frameSize.GetWidth() - OUTER_BORDER) / (MOUNTING_HOLES_COUNT + 1)
        addHole(board, toKiCADPoint((x, OUTER_BORDER / 2 + frameSize.GetY())), MOUNTING_HOLE_R)
        addHole(board, toKiCADPoint((x, - OUTER_BORDER / 2 +frameSize.GetY() + frameSize.GetHeight())), MOUNTING_HOLE_R)
    for i in range(MOUNTING_HOLES_COUNT):
        y = frameSize.GetY() + OUTER_BORDER / 2 + (i + 1) * (frameSize.GetHeight() - OUTER_BORDER) / (MOUNTING_HOLES_COUNT + 1)
        addHole(board, toKiCADPoint((OUTER_BORDER / 2 + frameSize.GetX(), y)), MOUNTING_HOLE_R)
        addHole(board, toKiCADPoint((- OUTER_BORDER / 2 +frameSize.GetX() + frameSize.GetWidth(), y)), MOUNTING_HOLE_R)

    PIN_TOLERANCE = fromMm(0.05)
    addHole(board, tl(frameSize) + toKiCADPoint((OUTER_BORDER / 2, OUTER_BORDER / 2)), MOUNTING_HOLE_R + PIN_TOLERANCE)
    addHole(board, tr(frameSize) + toKiCADPoint((-OUTER_BORDER / 2, OUTER_BORDER / 2)), MOUNTING_HOLE_R + PIN_TOLERANCE)
    addHole(board, br(frameSize) + toKiCADPoint((-OUTER_BORDER / 2, -OUTER_BORDER / 2)), MOUNTING_HOLE_R + PIN_TOLERANCE)
    addHole(board, bl(frameSize) + toKiCADPoint((OUTER_BORDER / 2, -OUTER_BORDER / 2)), MOUNTING_HOLE_R + PIN_TOLERANCE)
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

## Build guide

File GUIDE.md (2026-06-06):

# Nixie Clock — User Guide / Uživatelská příručka

A six-tube ESP32 nixie clock with WiFi, Home Assistant, a built-in web page,
alarm, and temperature display.

**🇬🇧 [English](#english) · 🇨🇿 [Čeština](#čeština)**

> Each language has two parts: **For everyone** (daily use) and **Power users**
> (network, MQTT, REST, building the firmware).
>
> Každý jazyk má dvě části: **Pro každého** (běžné používání) a **Pro pokročilé**
> (síť, MQTT, REST, sestavení firmwaru).

---

# English

## What it does

It shows the time on six nixie tubes and keeps it accurate over WiFi (internet
time sync). Even with no network it keeps running and keeps time thanks to its
built-in battery-backed clock chip. On top of the time it can:

- **Dim itself at night** on a schedule.
- **Show the temperature** for a few seconds at the end of each minute — from a
  plug-in sensor or pushed in from your smart home.
- **Wake you up** with an alarm (per-day-of-week, snooze, choice of melodies).
- Be controlled from your **phone or computer** (a web page) and from **Home
  Assistant**.
- **Protect the tubes** from "cathode poisoning" by cycling all digits
  periodically (keeps them bright for years).

## For everyone

### First start

1. Power the clock. The tubes do a "slot-machine" animation until it knows the
   time.
2. If it has never been set up, it starts its own WiFi network for setup — see
   **Connect it to your WiFi** below.
3. Once on your WiFi and time-synced, it just shows the time.

### Connect it to your WiFi

The clock can be set up entirely from your phone, no cable needed:

1. Put it in setup mode: **hold button 5** (the rightmost / provision button)
   for about **3 seconds** until it switches to setup.
2. The tubes show an **8-digit PIN** in two halves — the lit colon means you're
   looking at the first half, then it shows the second half.
3. On your phone, join the WiFi network called **`NixieClock-XXXXXX`**. When it
   asks for a password, type the 8-digit PIN from the tubes. (This way only
   someone standing at the clock can set it up.)
4. A setup page opens automatically. Pick your home WiFi, type its password,
   press save.
5. The clock reboots and connects to your network. Done.

> Lost track of the clock's address later? **Tap button 5 once** and it spells
> out its IP address on the tubes.

### The buttons

There are five buttons across the front (under tube positions 1–5) plus a
dedicated **snooze** button.

| Button | Tap | Hold |
|---|-----|---|
| **1** | Brightness up | — |
| **2** | Brightness down | — |
| **3** | Show temperature now | — |
| **4** | Run anti-poison cycle now | — |
| **5** | Show IP address | ~3 s: WiFi setup · ~10 s: factory reset |
| **Snooze** | Snooze the ringing alarm | Dismiss the alarm (until tomorrow) |

> **Handy combo:** hold **brightness up + down together** (~2 s) to toggle the
> alarm on or off.

### The web page

Open `http://<clock-ip>/` in any browser on the same network (find the IP by
tapping button 5). From there you can set:

- Brightness, and a **night schedule** (dimmer between, e.g., 20:30 and 06:00).
- **Alarm** — time, which days of the week, melody, snooze length. There's a
  **Play** button to preview the selected melody, and a **Status** line showing
  whether it's armed, snoozed, or off until the next ring.
- **Temperature** — turn it on, how many decimals, and which sensor feeds each
  of the two slots.
- **Network** — change WiFi / smart-home settings later without the PIN dance.

Changes apply instantly and stay in sync everywhere (web page, Home Assistant,
buttons all share the same settings).

### What the colon is telling you

The colon between the digits also signals the alarm state at a glance:

| Colon | Meaning |
|---|---|
| Normal blink / steady | Alarm off |
| One short pip per second | Alarm on |
| Two short pips per second | Snoozed (will ring again soon) |
| Whole display flashing | Alarm ringing now |

### Temperature sensors

The clock can show up to **two** temperatures near the end of each minute. Each
slot can be fed by either:

- a **plug-in DS18B20 sensor** (a small wired probe), or
- a value **pushed from your smart home** (e.g. the outdoor temperature).

If you plug in DS18B20 sensors, open the web page — every detected sensor is
listed with its **live reading** and an **Assign** button, so you don't have to
copy any codes by hand. Negative temperatures are shown by **blinking** the
reading (the tubes have no minus sign), and the colon acts as the decimal point.

### Factory reset

Hold **button 5 for ~10 seconds** (or use the button on the web page / Home
Assistant). This wipes all settings and WiFi credentials and returns the clock
to first-start setup mode. (The web/Home-Assistant button asks for confirmation
so it can't be triggered by accident.)

---

## Power users

Hardware: ESP32 (WROOM-32) on a **UCB32** controller driving a **Unidisp**
display board. RTC is a **PCF8563** at I²C `0x51` (the driver also auto-detects
DS1307/DS3231 at `0x68`). The HV supply has no dim input, so **brightness is
done in firmware** by PWM-ing each tube's anode within its multiplex slot.

Full pin map: [`components/common/include/pins.h`](components/common/include/pins.h).
Key lines: tube select `GPIO16/17/18`, BCD cathodes `GPIO23/25/26/27`, colon
`GPIO33`, buttons `GPIO14` (multiplexed, active-low) + snooze `GPIO15`, buzzer
`GPIO19`, I²C `GPIO21/22`, 1-Wire `GPIO13` (needs a **4.7 kΩ** pull-up to 3.3 V).

### Control surfaces

All three surfaces go through one shared settings store, so a change on any of
them is reflected on the others immediately.

#### Web UI + REST/JSON

Served by the clock itself at `http://<clock-ip>/`.

| Method & path | Purpose |
|---|---|
| `GET /api/state` | Full device state as JSON |
| `POST /api/set?k=<key>` | Set a setting; value in the request body |
| `POST /api/action?a=<action>` | Trigger an action; payload in body where noted |
| `GET /api/net` | Current network config |
| `POST /api/netset` | Update WiFi/MQTT credentials |

**Settings keys** (`/api/set?k=…`, value in body):

```
brightness            0..255
night_enabled         ON / OFF
night_brightness      0..255
night_start           HH:MM
night_end             HH:MM
blink_colon           ON / OFF
h24                   ON / OFF      (off = 12-hour, blanks leading zero)
ap_enabled            ON / OFF      (anti-poison enabled)
alarm_enabled         ON / OFF
alarm_time            HH:MM
alarm_melody          0..7          (see melody table)
alarm_snooze          minutes
alarm_dow             0..127        (bitmask: bit0=Sun … bit6=Sat; 0 = every day)
temp_enabled          ON / OFF
temp_decimals         0..2
temp1_source          none / mqtt / ds18b20
temp2_source          none / mqtt / ds18b20
temp1_rom             16-hex ROM    (empty string clears)
temp2_rom             16-hex ROM
```

**Actions** (`/api/action?a=…`):

```
antipoison_now        run the anti-poison cycle now
alarm_snooze          snooze a ringing alarm
alarm_dismiss         dismiss the alarm until tomorrow
alarm_test            preview the currently selected alarm melody once
mqtt_test             force an MQTT reconnect
temp1_input           push an MQTT-style value into slot 1 (value in body)
temp2_input           push a value into slot 2
factory_reset         wipe NVS + reboot — body MUST be the token "RESET"
```

`/api/state` returns, among others, a `ds` array listing every DS18B20 on the
bus with its live reading and assigned slot:

```json
"ds":[{"rom":"EE0623C3555D5028","t":"23.45","slot":1},
      {"rom":"9C0623C3452EE228","t":"21.10","slot":0}]
```

#### MQTT + Home Assistant

On connect the clock publishes **Home Assistant MQTT discovery** and appears as
a single *Nixie Clock* device (`nixie-<mac>`). Topic layout:

```
nixieclock/<node>/state            retained-ish JSON state (published on change)
nixieclock/<node>/availability     "online" / "offline" (LWT)
nixieclock/<node>/cmd/<key>        command topics — same keys as /api/set
homeassistant/.../config           discovery configs (retained)
```

Each discovered DS18B20 also gets its **own** temperature entity, regardless of
whether it's assigned to a display slot — so a sensor that only feeds Home
Assistant is still visible there. Its value comes from the `ds` object in the
state payload via a templated topic.

> Note: removing a DS18B20 leaves its retained discovery config behind; the
> entity goes *unavailable* rather than being auto-deleted.

Destructive commands are guarded: `factory_reset` requires the literal token
`RESET` in the payload, so a stray or retained message can't wipe the device.

### Credentials & provisioning

Credentials live in NVS. `components/common/include/secrets.h` (gitignored) is a
**first-boot fallback only** — once a WiFi SSID is stored in NVS the device
trusts NVS exclusively (an empty MQTT host means *no MQTT*, the client goes
idle). A factory reset erases NVS and forces SoftAP setup on the next boot,
regardless of `secrets.h`.

To seed defaults at compile time:

```sh
cp components/common/include/secrets.example.h components/common/include/secrets.h
# edit WIFI_SSID / WIFI_PASS / MQTT_*
```

### Build, flash, monitor

Requires [PlatformIO](https://platformio.org/install) (ESP-IDF 5.5). It fetches
the toolchain and managed components (`espressif/onewire_bus`, `espressif/ds18b20`)
on first build.

```sh
pio run                 # build
pio run -t upload       # build + flash over USB (serial / FTDI)
pio device monitor      # serial console @ 115200
```

> **No auto-reset on the board.** Before uploading, hand-enter download mode:
> **hold IO0, tap EN, release IO0.** Run only one upload at a time.

After adding/removing a component or editing a `REQUIRES`/`idf_component.yml`,
clear the stale CMake cache: `rm -rf .pio/build/esp32dev` then rebuild.

Flash layout: 4 MB, custom `partitions.csv` (single ~2.8 MB app + NVS + SPIFFS,
no OTA). App is ~37 % of the slot.

### Melody table (`alarm_melody`)

| # | Name | # | Name |
|---|---|---|---|
| 0 | Beep | 4 | Siren |
| 1 | Reveille | 5 | Nokia |
| 2 | Westminster | 6 | Axel F |
| 3 | Scale | 7 | Triad |

Melodies are RTTTL (Nokia ringtone format); the table lives in
[`components/buzzer/buzzer.c`](components/buzzer/buzzer.c).

### Display quirks (by design)

- **No decimal points** on the tubes — the colon between MM:SS is the only
  separator and doubles as the decimal point in temperature mode.
- **No minus glyph** — negative temperatures blink the whole reading.
- Brightness is multiplex duty-cycling; the cathode-before-anode write order and
  dead-time are the ghosting fix — don't reorder them.

---

# Čeština

## Co hodiny umí

Ukazují čas na šesti nixie tubicích a udržují ho přesný přes WiFi (synchronizace
času z internetu). I bez sítě běží dál a drží čas díky vestavěnému hodinovému
čipu se zálohovací baterií. Navíc umí:

- **Ztlumit se v noci** podle časového plánu.
- **Zobrazit teplotu** na pár vteřin na konci každé minuty — z připojeného
  čidla nebo poslanou z chytré domácnosti.
- **Vzbudit budíkem** (podle dne v týdnu, odložení, výběr melodií).
- Ovládat se z **telefonu nebo počítače** (webová stránka) a z **Home Assistanta**.
- **Chránit tubice** před „otravou katody" pravidelným protočením všech číslic
  (udrží je jasné po léta).

## Pro každého

### První spuštění

1. Připojte napájení. Tubice dělají „výherní automat", dokud hodiny neznají čas.
2. Pokud ještě nebyly nastaveny, spustí vlastní WiFi síť pro nastavení — viz
   **Připojení k WiFi** níže.
3. Jakmile jsou na vaší WiFi a mají synchronizovaný čas, jen ukazují čas.

### Připojení k WiFi

Hodiny se dají nastavit celé z telefonu, bez kabelu:

1. Přepněte je do režimu nastavení: **podržte tlačítko 5** (nejpravější /
   provisioning) asi **3 vteřiny**, dokud nepřejde do nastavení.
2. Tubice ukáží **8místný PIN** ve dvou polovinách — svítící dvojtečka znamená,
   že vidíte první polovinu, pak se ukáže druhá.
3. V telefonu se připojte k WiFi síti **`NixieClock-XXXXXX`**. Až se zeptá na
   heslo, zadejte 8místný PIN z tubic. (Takhle hodiny nastaví jen ten, kdo u
   nich stojí.)
4. Automaticky se otevře stránka nastavení. Vyberte svou domácí WiFi, zadejte
   heslo, uložte.
5. Hodiny se restartují a připojí k vaší síti. Hotovo.

> Zapomněli jste později adresu hodin? **Ťukněte jednou na tlačítko 5** a hodiny
> vypíší svou IP adresu na tubicích.

### Tlačítka

Vepředu je pět tlačítek (pod pozicemi tubic 1–5) plus vyhrazené tlačítko
**snooze** (odložení).

| Tlačítko | Ťuknutí | Podržení |
|---|---|---|
| **1** | Jas nahoru | — |
| **2** | Jas dolů | — |
| **3** | Ukázat teplotu hned | — |
| **4** | Spustit anti-poison cyklus | — |
| **5** | Ukázat IP adresu | ~3 s: nastavení WiFi · ~10 s: tovární reset |
| **Snooze** | Odložit zvonící budík | Vypnout budík (do zítřka) |

> **Šikovná kombinace:** podržte **jas nahoru + dolů zároveň** (~2 s) pro
> zapnutí/vypnutí budíku.

### Webová stránka

Otevřete `http://<ip-hodin>/` v jakémkoli prohlížeči ve stejné síti (IP zjistíte
ťuknutím na tlačítko 5). Můžete tam nastavit:

- Jas a **noční plán** (ztlumení např. mezi 20:30 a 06:00).
- **Budík** — čas, dny v týdnu, melodii, délku odložení. Je tu tlačítko **Play**
  pro přehrání vybrané melodie a řádek **Status**, který ukazuje, jestli je budík
  natažený, odložený, nebo vypnutý do dalšího zvonění.
- **Teplotu** — zapnutí, počet desetinných míst a které čidlo napájí každý ze
  dvou slotů.
- **Síť** — změnit WiFi / chytrou domácnost později bez tancování s PINem.

Změny se projeví okamžitě a zůstávají všude synchronizované (web, Home Assistant
i tlačítka sdílí stejné nastavení).

### Co vám napovídá dvojtečka

Dvojtečka mezi číslicemi také naznačuje stav budíku na první pohled:

| Dvojtečka | Význam |
|---|---|
| Normální blikání / svítí | Budík vypnutý |
| Jedno krátké bliknutí za vteřinu | Budík zapnutý |
| Dvě krátká bliknutí za vteřinu | Odložený (brzy zase zazvoní) |
| Bliká celý displej | Budík právě zvoní |

### Teplotní čidla

Hodiny umí ukázat až **dvě** teploty ke konci každé minuty. Každý slot může být
napájen buď:

- **připojeným čidlem DS18B20** (malá sonda na drátku), nebo
- hodnotou **poslanou z chytré domácnosti** (např. venkovní teplota).

Když připojíte čidla DS18B20, otevřete web — každé nalezené čidlo je v seznamu s
**živým náměrem** a tlačítkem **Assign** (přiřadit), takže nemusíte ručně
opisovat žádné kódy. Záporné teploty se ukazují **blikáním** náměru (tubice
nemají znaménko mínus) a dvojtečka slouží jako desetinná čárka.

### Tovární reset

Podržte **tlačítko 5 asi 10 vteřin** (nebo použijte tlačítko na webu / v Home
Assistantovi). Smaže všechna nastavení i WiFi údaje a vrátí hodiny do režimu
prvního nastavení. (Tlačítko na webu / v HA vyžaduje potvrzení, aby nešlo
spustit omylem.)

---

## Pro pokročilé

Hardware: ESP32 (WROOM-32) na řadiči **UCB32** ovládajícím zobrazovací desku
**Unidisp**. RTC je **PCF8563** na I²C `0x51` (ovladač auto-detekuje i
DS1307/DS3231 na `0x68`). Vysokonapěťový zdroj nemá vstup pro stmívání, takže se
**jas dělá ve firmwaru** PWM modulací anody každé tubice v jejím multiplexovém
okně.

Kompletní mapa pinů: [`components/common/include/pins.h`](components/common/include/pins.h).
Hlavní: výběr tubice `GPIO16/17/18`, BCD katody `GPIO23/25/26/27`, dvojtečka
`GPIO33`, tlačítka `GPIO14` (multiplexovaná, aktivní v nule) + snooze `GPIO15`,
bzučák `GPIO19`, I²C `GPIO21/22`, 1-Wire `GPIO13` (potřebuje **4,7 kΩ** pull-up
na 3,3 V).

### Ovládací rozhraní

Všechna tři rozhraní jdou přes jedno sdílené úložiště nastavení, takže změna na
kterémkoli se okamžitě projeví na ostatních.

#### Webové UI + REST/JSON

Hostují samy hodiny na `http://<ip-hodin>/`.

| Metoda a cesta | Účel |
|---|---|
| `GET /api/state` | Kompletní stav zařízení jako JSON |
| `POST /api/set?k=<klíč>` | Nastavit hodnotu; hodnota v těle požadavku |
| `POST /api/action?a=<akce>` | Spustit akci; data v těle kde je uvedeno |
| `GET /api/net` | Aktuální síťová konfigurace |
| `POST /api/netset` | Změnit WiFi/MQTT údaje |

**Klíče nastavení** (`/api/set?k=…`, hodnota v těle):

```
brightness            0..255
night_enabled         ON / OFF
night_brightness      0..255
night_start           HH:MM
night_end             HH:MM
blink_colon           ON / OFF
h24                   ON / OFF      (off = 12hodinový, skryje úvodní nulu)
ap_enabled            ON / OFF      (anti-poison zapnut)
alarm_enabled         ON / OFF
alarm_time            HH:MM
alarm_melody          0..7          (viz tabulka melodií)
alarm_snooze          minuty
alarm_dow             0..127        (bitmaska: bit0=Ne … bit6=So; 0 = každý den)
temp_enabled          ON / OFF
temp_decimals         0..2
temp1_source          none / mqtt / ds18b20
temp2_source          none / mqtt / ds18b20
temp1_rom             16 hex znaků ROM   (prázdný řetězec smaže)
temp2_rom             16 hex znaků ROM
```

**Akce** (`/api/action?a=…`):

```
antipoison_now        spustit anti-poison cyklus hned
alarm_snooze          odložit zvonící budík
alarm_dismiss         vypnout budík do zítřka
alarm_test            přehrát jednou aktuálně vybranou melodii budíku
mqtt_test             vynutit znovupřipojení MQTT
temp1_input           poslat MQTT hodnotu do slotu 1 (hodnota v těle)
temp2_input           poslat hodnotu do slotu 2
factory_reset         smazat NVS + restart — tělo MUSÍ být token "RESET"
```

`/api/state` mimo jiné vrací pole `ds` se všemi čidly DS18B20 na sběrnici, jejich
živým náměrem a přiřazeným slotem:

```json
"ds":[{"rom":"EE0623C3555D5028","t":"23.45","slot":1},
      {"rom":"9C0623C3452EE228","t":"21.10","slot":0}]
```

#### MQTT + Home Assistant

Po připojení hodiny publikují **Home Assistant MQTT discovery** a objeví se jako
jediné zařízení *Nixie Clock* (`nixie-<mac>`). Struktura topiců:

```
nixieclock/<node>/state            JSON stav (publikován při změně)
nixieclock/<node>/availability     "online" / "offline" (LWT)
nixieclock/<node>/cmd/<klíč>       příkazové topiky — stejné klíče jako /api/set
homeassistant/.../config           discovery konfigurace (retained)
```

Každé nalezené čidlo DS18B20 dostane i **vlastní** teplotní entitu, bez ohledu
na to, zda je přiřazené k zobrazovacímu slotu — takže čidlo, které jen napájí
Home Assistant, je tam stejně vidět. Jeho hodnota se bere z objektu `ds` ve
stavovém payloadu přes šablonovaný topic.

> Pozn.: odebrání čidla DS18B20 zanechá jeho retained discovery konfiguraci;
> entita přejde do stavu *nedostupná* místo automatického smazání.

Destruktivní příkazy jsou pojištěné: `factory_reset` vyžaduje v payloadu doslovný
token `RESET`, aby zatoulaná nebo retained zpráva nemohla zařízení smazat.

### Údaje a provisioning

Přihlašovací údaje jsou v NVS. `components/common/include/secrets.h` (gitignored)
je **pouze záloha pro první boot** — jakmile je v NVS uložené WiFi SSID, zařízení
důvěřuje výhradně NVS (prázdný MQTT host znamená *žádné MQTT*, klient se uspí).
Tovární reset smaže NVS a při dalším bootu vynutí SoftAP nastavení bez ohledu na
`secrets.h`.

Nasazení výchozích hodnot při kompilaci:

```sh
cp components/common/include/secrets.example.h components/common/include/secrets.h
# uprav WIFI_SSID / WIFI_PASS / MQTT_*
```

### Sestavení, flashování, monitor

Vyžaduje [PlatformIO](https://platformio.org/install) (ESP-IDF 5.5). Při prvním
buildu si stáhne toolchain a managed komponenty (`espressif/onewire_bus`,
`espressif/ds18b20`).

```sh
pio run                 # sestavit
pio run -t upload       # sestavit + flashnout přes USB (sériový port / FTDI)
pio device monitor      # sériová konzole @ 115200
```

> **Deska nemá auto-reset.** Před nahráním ručně vstupte do download módu:
> **podržte IO0, ťukněte EN, pusťte IO0.** Spouštějte vždy jen jeden upload.

Po přidání/odebrání komponenty nebo úpravě `REQUIRES`/`idf_component.yml` smažte
starou CMake cache: `rm -rf .pio/build/esp32dev` a sestavte znovu.

Rozložení flash: 4 MB, vlastní `partitions.csv` (jediná ~2,8 MB app + NVS +
SPIFFS, bez OTA). App zabírá ~37 % slotu.

### Tabulka melodií (`alarm_melody`)

| # | Název | # | Název |
|---|---|---|---|
| 0 | Beep | 4 | Siren |
| 1 | Reveille | 5 | Nokia |
| 2 | Westminster | 6 | Axel F |
| 3 | Scale | 7 | Triad |

Melodie jsou v RTTTL (formát Nokia vyzvánění); tabulka je v
[`components/buzzer/buzzer.c`](components/buzzer/buzzer.c).

### Zvláštnosti displeje (záměrné)

- **Žádné desetinné tečky** na tubicích — dvojtečka mezi MM:SS je jediný
  oddělovač a v režimu teploty slouží jako desetinná čárka.
- **Žádný znak mínus** — záporné teploty blikají celým náměrem.
- Jas je řízen střídou multiplexu; pořadí zápisu katoda-před-anodou a dead-time
  jsou oprava ghostingu — nepřehazovat.

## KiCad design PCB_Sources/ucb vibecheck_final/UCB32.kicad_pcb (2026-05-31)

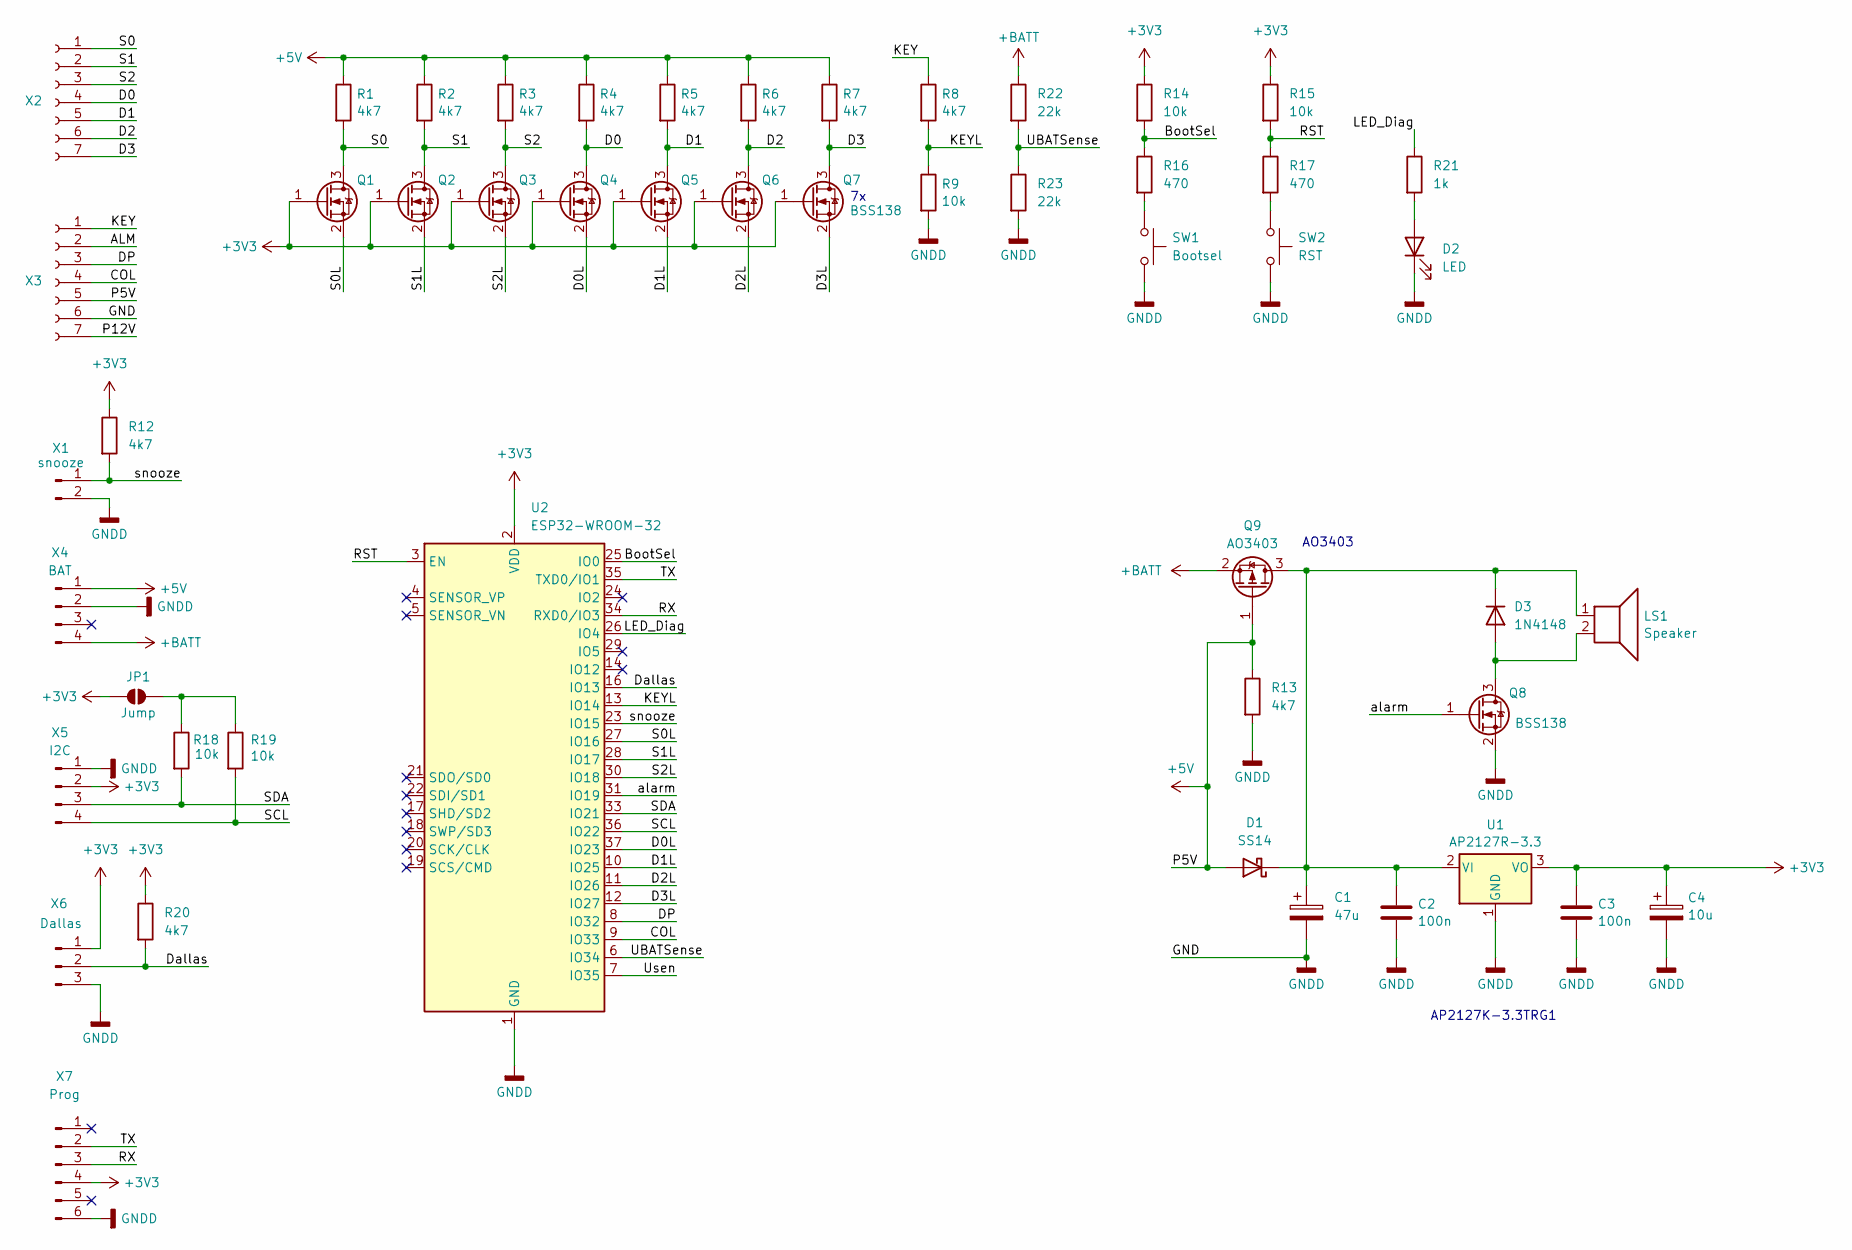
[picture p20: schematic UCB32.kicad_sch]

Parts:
C1: 47u; C_0805_2012Metric_Pad1.18x1.45mm_HandSolder
C2, C3: 100n; C_0805_2012Metric_Pad1.18x1.45mm_HandSolder
C4: 10u; C_0805_2012Metric_Pad1.18x1.45mm_HandSolder
D1: SS14; D_SMA
D2: LED; LED_0805_2012Metric_Pad1.15x1.40mm_HandSolder
D3: 1N4148; D_MiniMELF
JP1: Jump; SolderJumper-2_P1.3mm_Open_TrianglePad1.0x1.5mm
LS1: Speaker; Buzzer_TDK_PS1240P02BT_D12.2mm_H6.5mm
Q1, Q2, Q3, Q4, Q5, Q6, Q7, Q8: BSS138; SOT-23
Q9: AO3403; SOT-23
R1, R2, R3, R4, R5, R6, R7, R8, R12, R13, R20: 4k7; R_0805_2012Metric_Pad1.20x1.40mm_HandSolder
R9, R14, R15, R18, R19: 10k; R_0805_2012Metric_Pad1.20x1.40mm_HandSolder
R16, R17: 470; R_0805_2012Metric_Pad1.20x1.40mm_HandSolder
R21: 1k; R_0805_2012Metric_Pad1.20x1.40mm_HandSolder
R22, R23: 22k; R_0805_2012Metric_Pad1.20x1.40mm_HandSolder
SW1: Bootsel; SW_SPST_CK_RS282G05A3
SW2: RST; SW_SPST_CK_RS282G05A3
U1: AP2127R-3.3; SOT-89-3
U2: ESP32-WROOM-32
X1: snooze; PinHeader_1x02_P2.54mm_Vertical
X2, X3: Conn_01x07_Socket; PinSocket_1x07_P2.54mm_Vertical
X4: BAT; JST_XH_B4B-XH-A_1x04_P2.50mm_Vertical
X5: I2C; PinHeader_1x04_P2.54mm_Vertical
X6: Dallas; PinHeader_1x03_P2.54mm_Vertical
X7: Prog; PinSocket_1x06_P2.54mm_Vertical

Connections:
+3V3: C3.1, C4.1, JP1.1 (A), Q1.1 (G), Q2.1 (G), Q3.1 (G), Q4.1 (G), Q5.1 (G), Q6.1 (G), Q7.1 (G), R12.1, R14.1, R15.1, R20.1, U1.3 (VO), U2.2 (VDD), X5.2, X6.1, X7.4
+5V: D1.2 (A), Q9.1 (G), R1.1, R2.1, R3.1, R4.1, R5.1, R6.1, R7.1, R13.1, X3.5, X4.1
+BATT: Q9.2 (S), R22.1, X4.4
/ALM: X3.2
/BootSel: R14.2, R16.1, U2.25 (IO0)
/COL: U2.9 (IO33), X3.4
/D0: Q4.3 (D), R4.2, X2.4
/D0L: Q4.2 (S), U2.37 (IO23)
/D1: Q5.3 (D), R5.2, X2.5
/D1L: Q5.2 (S), U2.10 (IO25)
/D2: Q6.3 (D), R6.2, X2.6
/D2L: Q6.2 (S), U2.11 (IO26)
/D3: Q7.3 (D), R7.2, X2.7
/D3L: Q7.2 (S), U2.12 (IO27)
/DP: U2.8 (IO32), X3.3
/Dallas: R20.2, U2.16 (IO13), X6.2
/KEY: R8.1, X3.1
/KEYL: R8.2, R9.1, U2.13 (IO14)
/LED_Diag: R21.1, U2.26 (IO4)
/P12V: X3.7
/RST: R15.2, R17.1, U2.3 (EN)
/RX: U2.34 (RXD0/IO3), X7.3
/S0: Q1.3 (D), R1.2, X2.1
/S0L: Q1.2 (S), U2.27 (IO16)
/S1: Q2.3 (D), R2.2, X2.2
/S1L: Q2.2 (S), U2.28 (IO17)
/S2: Q3.3 (D), R3.2, X2.3
/S2L: Q3.2 (S), U2.30 (IO18)
/SCL: R19.2, U2.36 (IO22), X5.4
/SDA: R18.2, U2.33 (IO21), X5.3
/TX: U2.35 (TXD0/IO1), X7.2
/UBATSense: R22.2, R23.1, U2.6 (IO34)
/Usen: U2.7 (IO35)
/alarm: Q8.1 (G), U2.31 (IO19)
/snooze: R12.2, U2.23 (IO15), X1.1
GNDD: C1.2, C2.2, C3.2, C4.2, D2.1 (K), Q8.2 (S), R9.2, R13.2, R23.2, SW1.2, SW2.2, U1.1 (GND), U2.1 (GND), U2.15 (GND), U2.38 (GND), U2.39 (GND), X1.2, X3.6, X4.2, X5.1, X6.3, X7.6
unnamed: C1.1, C2.1, D1.1 (K), D3.1 (K), LS1.1, Q9.3 (D), U1.2 (VI)
unnamed: D2.2 (A), R21.2
unnamed: D3.2 (A), LS1.2, Q8.3 (D)
unnamed: JP1.2 (B), R18.1, R19.1
unnamed: R16.2, SW1.1
unnamed: R17.2, SW2.1

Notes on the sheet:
AO3403
AP2127K-3.3TRG1

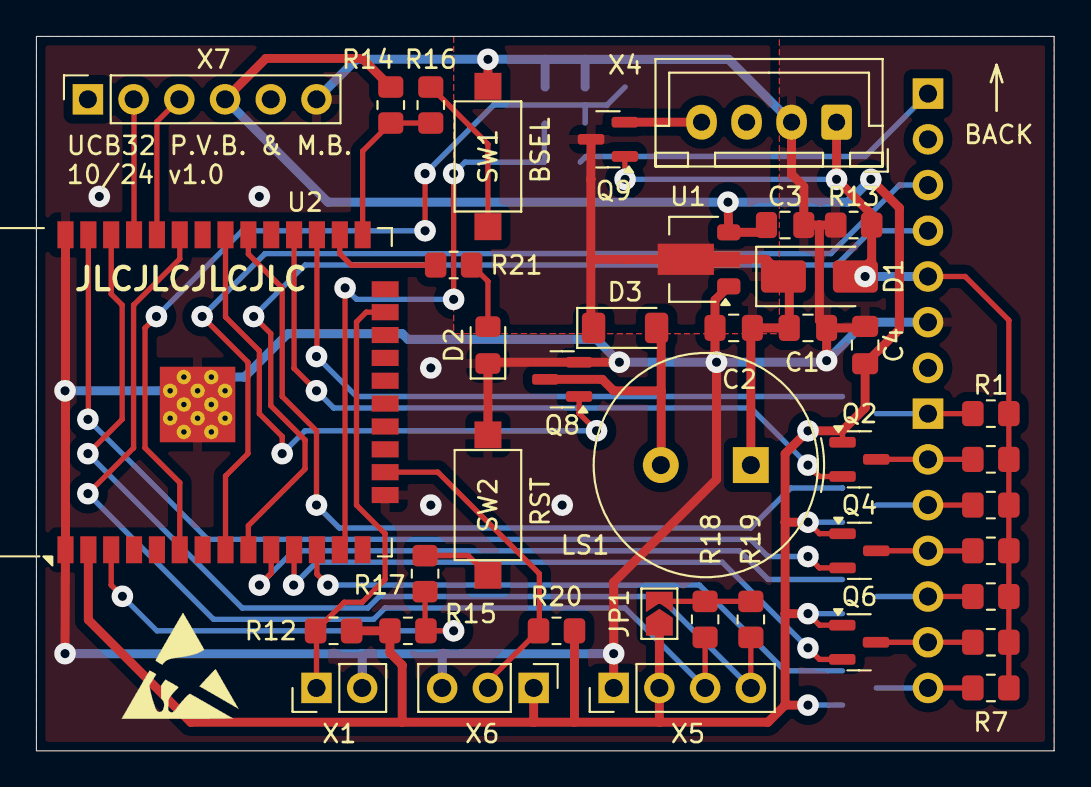
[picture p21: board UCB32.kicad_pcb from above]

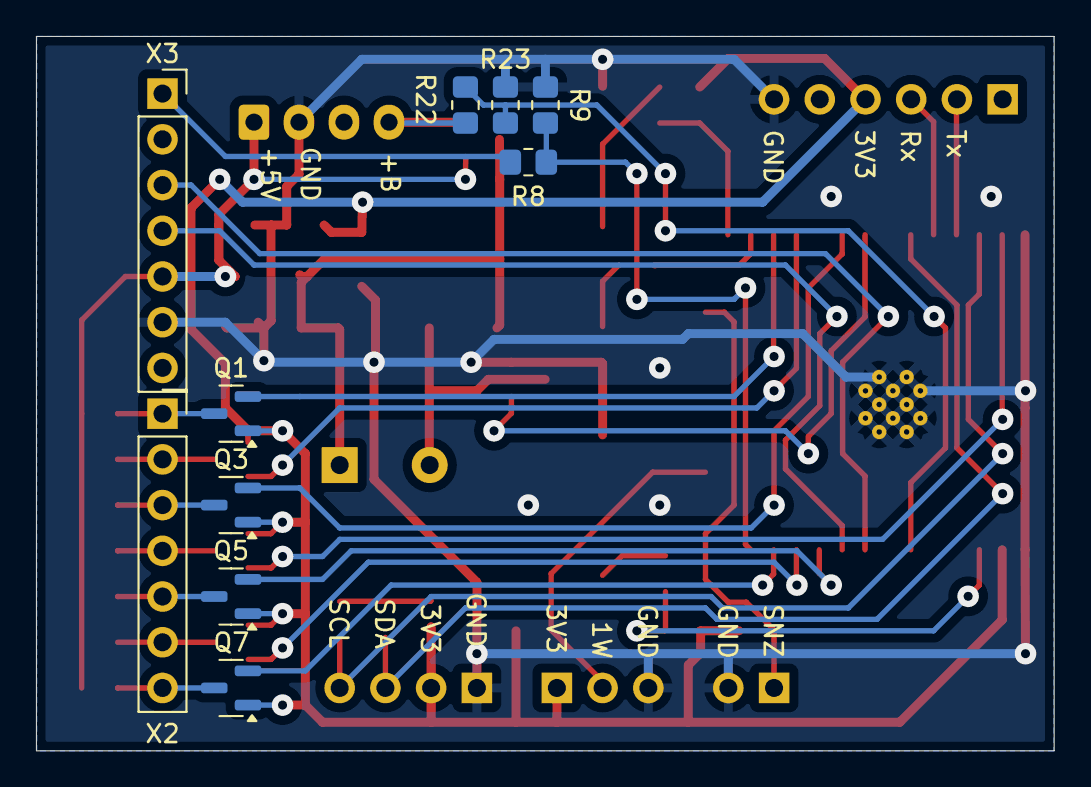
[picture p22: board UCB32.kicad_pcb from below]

Board: 2 copper layers, 56.5 x 39.7 mm, 50 parts (10 on the bottom side), 39 nets.

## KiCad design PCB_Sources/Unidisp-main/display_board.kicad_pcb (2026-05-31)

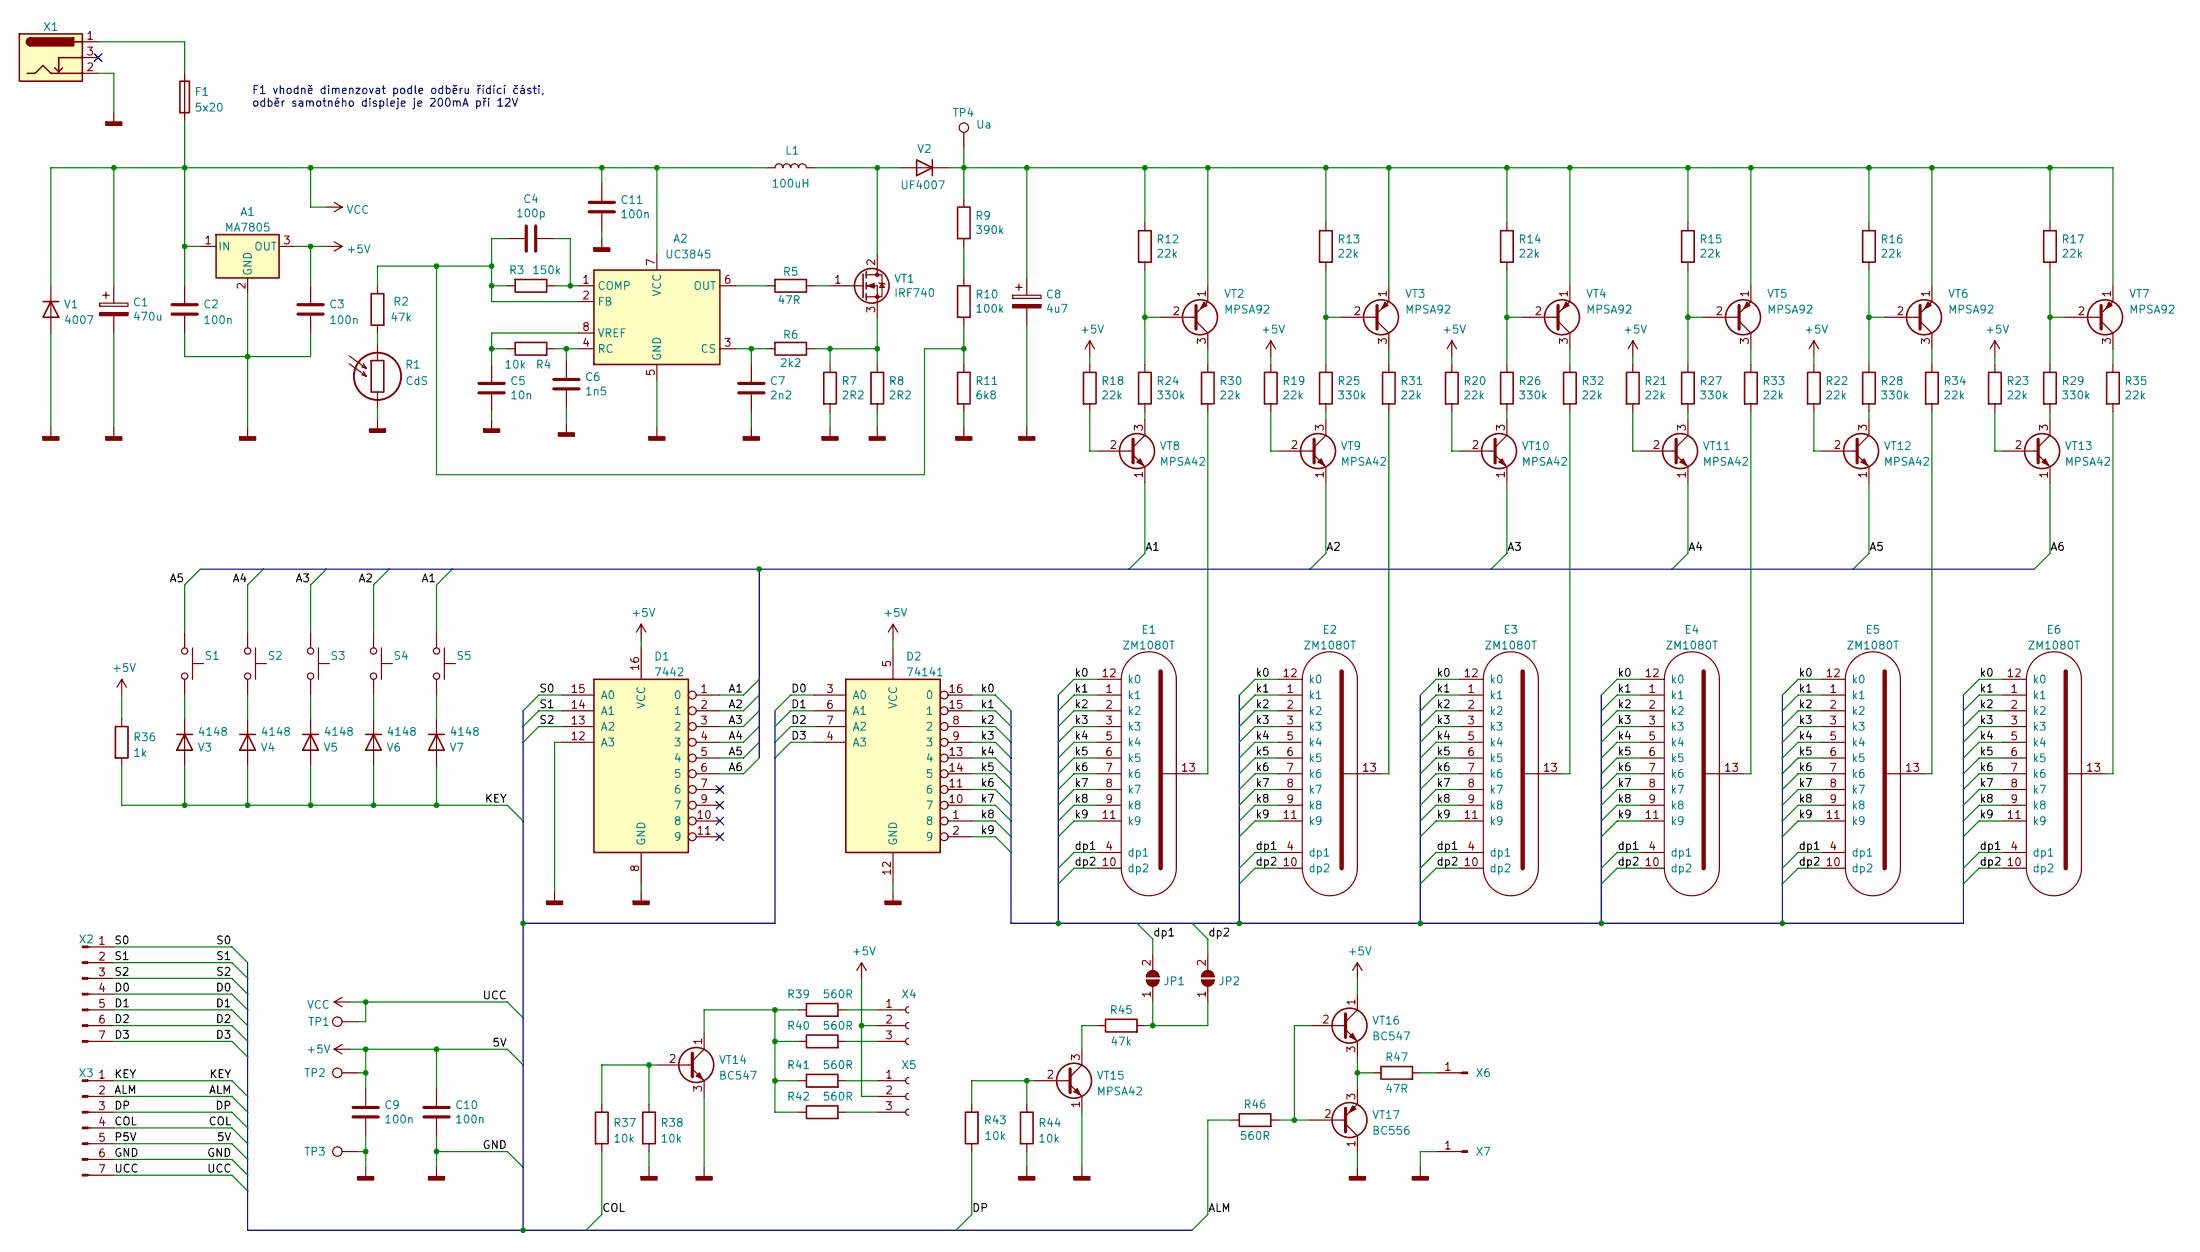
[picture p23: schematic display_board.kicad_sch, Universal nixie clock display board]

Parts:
A1: MA7805; TO-3_78xx
A2: UC3845; DIP-8_W7.62mm
C1: 470u; CP_Radial_D8.0mm_P3.80mm
C2, C3, C9, C10, C11: 100n; C_Disc_D4.3mm_W1.9mm_P5.00mm
C4: 100p; C_Disc_D4.3mm_W1.9mm_P5.00mm
C5: 10n; C_Disc_D4.3mm_W1.9mm_P5.00mm
C6: 1n5; C_Disc_D4.3mm_W1.9mm_P5.00mm
C7: 2n2; C_Disc_D4.3mm_W1.9mm_P5.00mm
C8: 4u7; CP_Radial_D10.0mm_P3.80mm
D1: 7442; DIP-16_W7.62mm
D2: 74141; DIP-16_W7.62mm
E1, E2, E3, E4, E5, E6: ZM1080T; nixie_13pin
F1: 5x20; Fuseholder_Cylinder-5x20mm_Stelvio-Kontek_PTF76_Horizontal_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
JP1, JP2: SolderJumper_2_Open; SolderJumper-2_P1.3mm_Open_Pad1.0x1.5mm
L1: 100uH; L_Radial_D8.7mm_P5.00mm_Fastron_07HCP
R1: CdS; R_LDR_D6.4mm_P3.4mm_Vertical
R2, R45: 47k; R DIN0207 10.16mm
R3: 150k; R DIN0207 10.16mm
R4, R37, R38, R43, R44: 10k; R DIN0207 10.16mm
R5, R47: 47R; R DIN0207 10.16mm
R6: 2k2; R DIN0207 10.16mm
R7, R8: 2R2; R DIN0207 10.16mm
R9: 390k; R DIN0207 10.16mm
R10: 100k; R DIN0207 10.16mm
R11: 6k8; R DIN0207 10.16mm
R12, R13, R14, R15, R16, R17, R18, R19, R20, R21, R22, R23, R30, R31, R32, R33, R34, R35: 22k; R DIN0207 10.16mm
R24, R25, R26, R27, R28, R29: 330k; R DIN0207 10.16mm
R36: 1k; R DIN0207 10.16mm
R39, R40, R41, R42, R46: 560R; R DIN0207 10.16mm
S1, S2, S3, S4, S5: SW_Push; SW_Tactile_SPST_Angled_PTS645Vx58-2LFS
TP1: Vcc; TestPoint_THTPad_D3.0mm_Drill1.5mm
TP2: +5V; TestPoint_THTPad_D3.0mm_Drill1.5mm
TP3: GND; TestPoint_THTPad_D3.0mm_Drill1.5mm
TP4: Ua; TestPoint_THTPad_D3.0mm_Drill1.5mm
V1: 4007; D_DO-41_SOD81_P10.16mm_Horizontal
V2: UF4007; D_DO-41_SOD81_P10.16mm_Horizontal
V3, V4, V5, V6, V7: 4148; D_DO-35_SOD27_P10.16mm_Horizontal
VT1: IRF740; TO-220-3_Horizontal_TabDown
VT2, VT3, VT4, VT5, VT6, VT7: MPSA92; TO-92_Wide
VT8, VT9, VT10, VT11, VT12, VT13, VT15: MPSA42; TO-92_Wide
VT14, VT16: BC547; TO-92_Wide
VT17: BC556; TO-92_Wide
X1: Barrel_Jack_Switch; BarrelJack_Horizontal
X2, X3: Conn_01x07_Male; PinHeader_1x07_P2.54mm_Vertical
X4, X5: Conn_01x03_Female; PinSocket_1x03_P2.54mm_Vertical
X6, X7: Conn_01x01_Male; PinHeader_1x01_P2.54mm_Vertical

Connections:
+5V: A1.3 (OUT), C3.1, C9.1, C10.1, D1.16 (VCC), D2.5 (VCC), R18.1, R19.1, R20.1, R21.1, R22.1, R23.1, R36.1, TP2.1, VT16.1 (C), X3.5, X4.2, X5.2
/A1: D1.1 (0), S5.1, VT8.1 (E)
/A2: D1.2 (1), S4.1, VT9.1 (E)
/A3: D1.3 (2), S3.1, VT10.1 (E)
/A4: D1.4 (3), S2.1, VT11.1 (E)
/A5: D1.5 (4), S1.1, VT12.1 (E)
/A6: D1.6 (5), VT13.1 (E)
/ALM: R46.1, X3.2
/COL: R37.2, X3.4
/D0: D2.3 (A0), X2.4
/D1: D2.6 (A1), X2.5
/D2: D2.7 (A2), X2.6
/D3: D2.4 (A3), X2.7
/DP: R43.1, X3.3
/KEY: R36.2, V3.2 (A), V4.2 (A), V5.2 (A), V6.2 (A), V7.2 (A), X3.1
/S0: D1.15 (A0), X2.1
/S1: D1.14 (A1), X2.2
/S2: D1.13 (A2), X2.3
/dp1: E1.4 (dp1), E2.4 (dp1), E3.4 (dp1), E4.4 (dp1), E5.4 (dp1), E6.4 (dp1), JP1.2 (B)
/dp2: E1.10 (dp2), E2.10 (dp2), E3.10 (dp2), E4.10 (dp2), E5.10 (dp2), E6.10 (dp2), JP2.2 (B)
/k0: D2.16 (0), E1.12 (k0), E2.12 (k0), E3.12 (k0), E4.12 (k0), E5.12 (k0), E6.12 (k0)
/k1: D2.15 (1), E1.1 (k1), E2.1 (k1), E3.1 (k1), E4.1 (k1), E5.1 (k1), E6.1 (k1)
/k2: D2.8 (2), E1.2 (k2), E2.2 (k2), E3.2 (k2), E4.2 (k2), E5.2 (k2), E6.2 (k2)
/k3: D2.9 (3), E1.3 (k3), E2.3 (k3), E3.3 (k3), E4.3 (k3), E5.3 (k3), E6.3 (k3)
/k4: D2.13 (4), E1.5 (k4), E2.5 (k4), E3.5 (k4), E4.5 (k4), E5.5 (k4), E6.5 (k4)
/k5: D2.14 (5), E1.6 (k5), E2.6 (k5), E3.6 (k5), E4.6 (k5), E5.6 (k5), E6.6 (k5)
/k6: D2.11 (6), E1.7 (k6), E2.7 (k6), E3.7 (k6), E4.7 (k6), E5.7 (k6), E6.7 (k6)
/k7: D2.10 (7), E1.8 (k7), E2.8 (k7), E3.8 (k7), E4.8 (k7), E5.8 (k7), E6.8 (k7)
/k8: D2.1 (8), E1.9 (k8), E2.9 (k8), E3.9 (k8), E4.9 (k8), E5.9 (k8), E6.9 (k8)
/k9: D2.2 (9), E1.11 (k9), E2.11 (k9), E3.11 (k9), E4.11 (k9), E5.11 (k9), E6.11 (k9)
GNDD: A1.2 (GND), A2.5 (GND), C1.2, C2.2, C3.2, C5.2, C6.2, C7.2, C8.2, C9.2, C10.2, C11.2, D1.8 (GND), D1.12 (A3), D2.12 (GND), R1.2, R7.2, R8.2, R11.2, R38.2, R44.2, TP3.1, V1.2 (A), VT14.3 (E), VT15.1 (E), VT17.1 (C), X1.2, X3.6, X7.1
unnamed: A2.1 (COMP), C4.1, R3.1
unnamed: A2.2 (FB), C4.2, R2.1, R3.2, R10.2, R11.1
unnamed: A2.3 (CS), C7.1, R6.2
unnamed: A2.4 (RC), C6.1, R4.2
unnamed: A2.6 (OUT), R5.2
unnamed: A2.8 (VREF), C5.1, R4.1
unnamed: C8.1, R9.1, R12.1, R13.1, R14.1, R15.1, R16.1, R17.1, TP4.1, V2.1 (K), VT2.1 (E), VT3.1 (E), VT4.1 (E), VT5.1 (E), VT6.1 (E), VT7.1 (E)
unnamed: E1.13, R30.2
unnamed: E2.13, R31.2
unnamed: E3.13, R32.2
unnamed: E4.13, R33.2
unnamed: E5.13, R34.2
unnamed: E6.13, R35.2
unnamed: F1.1, X1.1
unnamed: JP1.1 (A), JP2.1 (A), R45.2
unnamed: L1.2, V2.2 (A), VT1.2 (D)
unnamed: R1.1, R2.2
unnamed: R5.1, VT1.1 (G)
unnamed: R6.1, R7.1, R8.1, VT1.3 (S)
unnamed: R9.2, R10.1
unnamed: R12.2, R24.1, VT2.2 (B)
unnamed: R13.2, R25.1, VT3.2 (B)
unnamed: R14.2, R26.1, VT4.2 (B)
unnamed: R15.2, R27.1, VT5.2 (B)
unnamed: R16.2, R28.1, VT6.2 (B)
unnamed: R17.2, R29.1, VT7.2 (B)
unnamed: R18.2, VT8.2 (B)
unnamed: R19.2, VT9.2 (B)
unnamed: R20.2, VT10.2 (B)
unnamed: R21.2, VT11.2 (B)
unnamed: R22.2, VT12.2 (B)
unnamed: R23.2, VT13.2 (B)
unnamed: R24.2, VT8.3 (C)
unnamed: R25.2, VT9.3 (C)
unnamed: R26.2, VT10.3 (C)
unnamed: R27.2, VT11.3 (C)
unnamed: R28.2, VT12.3 (C)
unnamed: R29.2, VT13.3 (C)
unnamed: R30.1, VT2.3 (C)
unnamed: R31.1, VT3.3 (C)
unnamed: R32.1, VT4.3 (C)
unnamed: R33.1, VT5.3 (C)
unnamed: R34.1, VT6.3 (C)
unnamed: R35.1, VT7.3 (C)
unnamed: R37.1, R38.1, VT14.2 (B)
unnamed: R39.1, R40.1, R41.1, R42.1, VT14.1 (C)
unnamed: R39.2, X4.1
unnamed: R40.2, X4.3
unnamed: R41.2, X5.1
unnamed: R42.2, X5.3
unnamed: R43.2, R44.1, VT15.2 (B)
unnamed: R45.1, VT15.3 (C)
unnamed: R46.2, VT16.2 (B), VT17.2 (B)
unnamed: R47.1, VT16.3 (E), VT17.3 (E)
unnamed: R47.2, X6.1
unnamed: S1.2, V3.1 (K)
unnamed: S2.2, V4.1 (K)
unnamed: S3.2, V5.1 (K)
unnamed: S4.2, V6.1 (K)
unnamed: S5.2, V7.1 (K)
VCC: A1.1 (IN), A2.7 (VCC), C1.1, C2.1, C11.1, F1.2, L1.1, TP1.1, V1.1 (K), X3.7

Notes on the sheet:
F1 vhodně dimenzovat podle odběru řídící části, odběr samotného displeje je 200mA při 12V

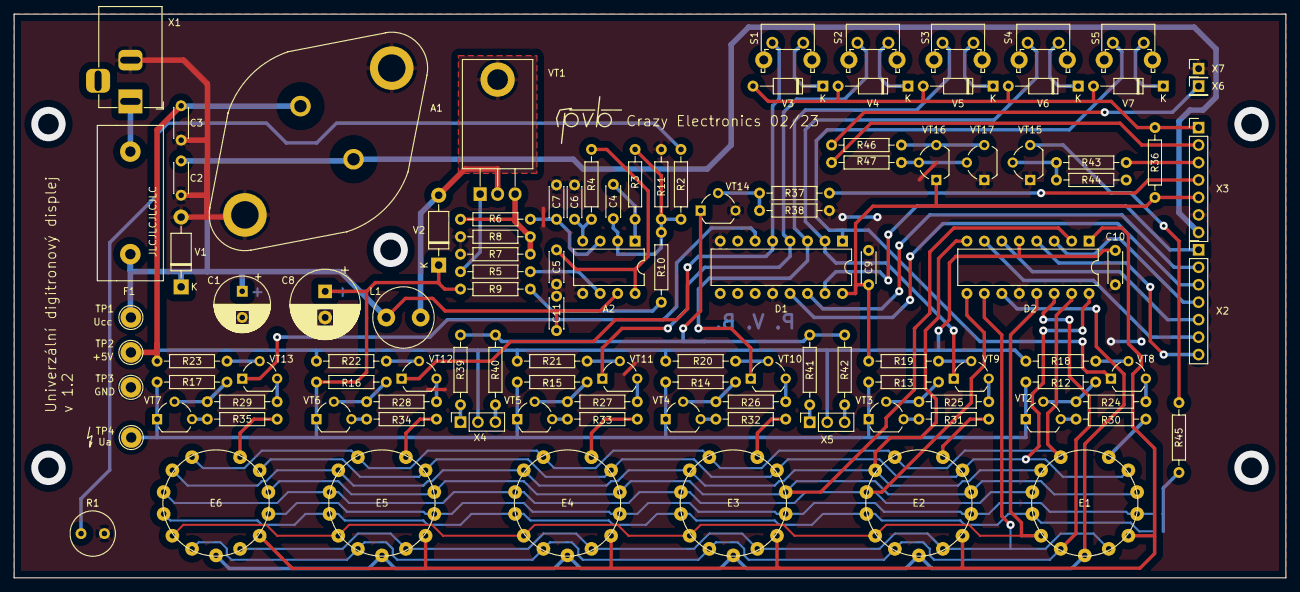
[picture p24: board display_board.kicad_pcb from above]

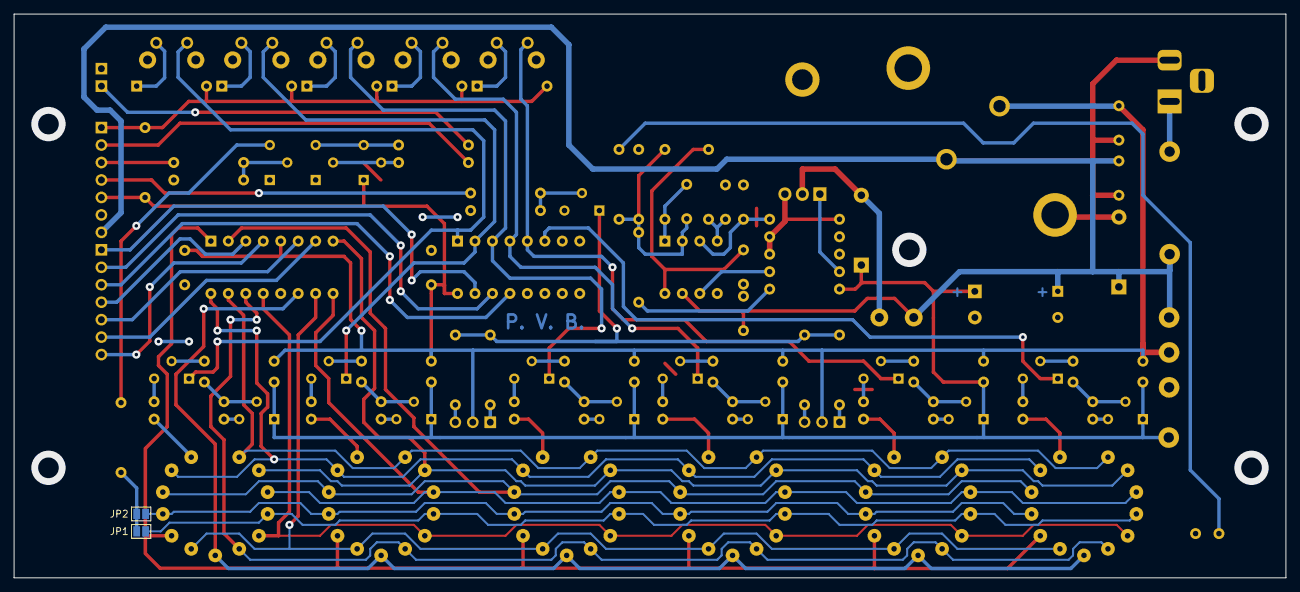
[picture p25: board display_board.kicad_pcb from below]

Board: 2 copper layers, 185.0 x 82.0 mm, 112 parts (2 on the bottom side), 92 nets.

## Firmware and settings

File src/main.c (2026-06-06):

// NixieClock firmware — entry point.
//
// Time source of truth = the ESP's own system clock (time()/localtime_r). Two
// things feed it, so the clock is robust whether or not either is present:
//   - SNTP over WiFi sets the system clock (and mirrors it into the RTC).
//   - At boot, if the RTC holds a valid time, we seed the system clock from it
//     so the correct time shows immediately, before WiFi/SNTP comes up.
//
// Display behaviour is driven by the persisted settings store:
//   - brightness = manual level, or the night level inside the night window,
//     or (future) a BH1750 reading when auto-brightness is on;
//   - colon blink / 12-24h format are settings too;
//   - anti-poison period/duration come from settings;
//   - near the end of each minute the display briefly shows temperature slots.
// When the system clock has no valid time yet (cold boot, no RTC, pre-sync) we
// run the "slot-machine" animation so you can see the clock is alive.
#include "nixie.h"
#include "rtc_clock.h"
#include "i2cbus.h"
#include "netclock.h"
#include "antipoison.h"
#include "settings.h"
#include "mqttctrl.h"
#include "temps.h"
#include "buttons.h"
#include "alarm.h"
#include "buzzer.h"
#include "webui.h"
#include "provision.h"
#include "netcfg.h"

#include <time.h>
#include <sys/time.h>

#include "freertos/FreeRTOS.h"
#include "freertos/task.h"
#include "esp_timer.h"
#include "esp_log.h"
#include "nvs_flash.h"
#include "esp_mac.h"
#include "esp_netif.h"
#include "esp_netif_ip_addr.h"
#include <stdio.h>

static const char *TAG = "main";

#define LOOP_MS         50
#define MIN_VALID_YEAR  2023   // tm_year+1900 below this => time not set yet
#define NO_SENSOR       (-1)   // BH1750 not present/enabled yet
#define BRIGHT_STEP     25     // button brightness increment
#define SHOW_TEMP_MS    4000   // "show temp now" duration (2s per slot)
#define CONFIRM_MS      1000   // dismiss-confirm blink window (~2 blinks @250ms)
#define IP_OCTET_MS     1000   // per-octet dwell when showing the IP
#define IP_GAP_MS        250   // brief blank between octets

// Set by the SHOW_TEMP button: while now_ms < this, the display forces the
// temperature slots regardless of the normal :52-:55 schedule.
static volatile int64_t s_force_temp_until;
// Set on alarm dismiss: blink the time a couple times to confirm the long-press.
static volatile int64_t s_confirm_until;
// Set by the SHOW_IP button: walk the 4 IP octets across the tubes until this.
static volatile int64_t s_show_ip_until;
static uint8_t s_ip_octet[4];   // captured at press time

// Push the anti-poison period/duration from settings into the routine.
static void apply_antipoison(const clock_settings_t *c)
{
    antipoison_set_period_s(c->ap_enabled ? c->ap_period_s : 0);
    antipoison_set_duration_ms(c->ap_duration_ms);
}

// Fill the framebuffer with HH MM SS, left to right (idx 0 = hours-tens).
static void show_time(const struct tm *lt, bool h24)
{
    int hour = lt->tm_hour;
    bool blank_h_tens = false;
    if (!h24) {
        hour %= 12;
        if (hour == 0) hour = 12;
        blank_h_tens = (hour < 10);   // 12-hour: no leading zero on hours
    }

    uint8_t d[NIXIE_NUM_TUBES] = {
        (uint8_t)(hour / 10), (uint8_t)(hour % 10),
        (uint8_t)(lt->tm_min / 10), (uint8_t)(lt->tm_min % 10),
        (uint8_t)(lt->tm_sec / 10), (uint8_t)(lt->tm_sec % 10),
    };
    if (blank_h_tens) d[0] = NIXIE_BLANK;
    nixie_set_digits(d);
}

// Show a temperature (centi-degrees C) right-aligned on the tubes. These tubes
// have NO per-digit decimal points, so the colon (the only separator, between
// the MM:SS pair = tubes 3|4) is lit steady to act as the decimal point: a
// 2-decimal reading 23.45 lands as 2 3 : 4 5. This function drives the colon
// itself. No minus glyph exists, so negative values blink the whole reading
// (digits + colon) at ~2 Hz.
static void show_temp(int16_t centi, uint8_t decimals, int64_t now_ms)
{
    bool neg = centi < 0;
    int v = neg ? -centi : centi;          // magnitude, centi-degrees
    if (v > 9999) v = 9999;                // clamp to what 4 tubes can show

    uint8_t d[NIXIE_NUM_TUBES] = {
        NIXIE_BLANK, NIXIE_BLANK, NIXIE_BLANK,
        NIXIE_BLANK, NIXIE_BLANK, NIXIE_BLANK
    };

    // Negative + blink "off" phase: show nothing this frame (colon off too).
    if (neg && ((now_ms / 250) % 2 != 0)) {
        nixie_set_digits(d);
        nixie_set_colon(false);
        return;
    }

    bool colon = false;
    if (decimals >= 2) {
        int integer = v / 100, frac = v % 100;
        d[5] = frac % 10;
        d[4] = (frac / 10) % 10;
        d[3] = integer % 10;
        if (integer >= 10) d[2] = (integer / 10) % 10;
        colon = true;                      // colon sits between tubes 3|4 = the point
    } else if (decimals == 1) {
        int t = (v + 5) / 10;              // round to tenths
        int integer = t / 10, tenth = t % 10;
        d[4] = tenth;
        d[3] = integer % 10;
        if (integer >= 10) d[2] = (integer / 10) % 10;
        colon = true;
    } else {
        int deg = (v + 50) / 100;          // round to whole degrees
        d[5] = deg % 10;
        if (deg >= 10) d[4] = (deg / 10) % 10;
        colon = false;                     // whole degrees: no decimal point
    }
    nixie_set_digits(d);
    nixie_set_colon(colon);
}

// "Alive but unset": every tube shows the same digit, cycling 0->9.
static void show_slot_machine(uint8_t step)
{
    uint8_t d = step % 10;
    uint8_t all[NIXIE_NUM_TUBES] = { d, d, d, d, d, d };
    nixie_set_digits(all);
}

// All tubes off (for the ringing/confirm flash "off" phase).
static void show_blank(void)
{
    uint8_t all[NIXIE_NUM_TUBES] = {
        NIXIE_BLANK, NIXIE_BLANK, NIXIE_BLANK,
        NIXIE_BLANK, NIXIE_BLANK, NIXIE_BLANK
    };
    nixie_set_digits(all);
}

// Show one IP octet (0..255) right-aligned, leading tubes blank. e.g. 192 ->
// "xxx192", 3 -> "xxxxx3". Colon off; this is a status readout, not a time.
static void show_octet(uint8_t v)
{
    uint8_t d[NIXIE_NUM_TUBES] = {
        NIXIE_BLANK, NIXIE_BLANK, NIXIE_BLANK,
        NIXIE_BLANK, NIXIE_BLANK, NIXIE_BLANK
    };
    d[5] = v % 10;
    if (v >= 10)  d[4] = (v / 10) % 10;
    if (v >= 100) d[3] = (v / 100) % 10;
    nixie_set_digits(d);
    nixie_set_colon(false);
}

// Capture the current STA IPv4 octets for the SHOW_IP readout. Returns false if
// we have no IP yet (not connected).
static bool capture_ip(uint8_t out[4])
{
    esp_netif_t *nif = esp_netif_get_handle_from_ifkey("WIFI_STA_DEF");
    esp_netif_ip_info_t ip;
    if (!nif || esp_netif_get_ip_info(nif, &ip) != ESP_OK) return false;
    if (ip.ip.addr == 0) return false;
    out[0] = esp_ip4_addr1_16(&ip.ip);
    out[1] = esp_ip4_addr2_16(&ip.ip);
    out[2] = esp_ip4_addr3_16(&ip.ip);
    out[3] = esp_ip4_addr4_16(&ip.ip);
    return true;
}

// If the RTC has a believable time, copy it into the ESP system clock so the
// display is correct from the first second, before SNTP has had a chance.
static void seed_system_clock_from_rtc(void)
{
    rtc_time_t r;
    if (rtc_get(&r) != ESP_OK || !rtc_time_valid(&r)) return;

    struct tm tm = {
        .tm_year = r.year - 1900,
        .tm_mon  = r.month - 1,
        .tm_mday = r.day,
        .tm_hour = r.hour,
        .tm_min  = r.minute,
        .tm_sec  = r.second,
        .tm_isdst = -1,
    };
    time_t epoch = mktime(&tm);            // interprets tm as local (TZ already set)
    struct timeval tv = { .tv_sec = epoch, .tv_usec = 0 };
    settimeofday(&tv, NULL);
    ESP_LOGI(TAG, "system clock seeded from RTC");
}

// Slot 0 shows at seconds 52-53, slot 1 at 54-55, else -1 (show the time).
static int temp_slot_for_second(int sec)
{
    if (sec == 52 || sec == 53) return 0;
    if (sec == 54 || sec == 55) return 1;
    return -1;
}

// Adjust the persisted manual brightness by `delta`, clamped to 0..255.
static void nudge_brightness(int delta)
{
    clock_settings_t c;
    settings_get(&c);
    int v = (int)c.brightness + delta;
    if (v < 0) v = 0;
    if (v > 255) v = 255;
    c.brightness = (uint8_t)v;
    settings_set(&c);   // bumps version -> main loop re-applies + MQTT echoes
    ESP_LOGI(TAG, "brightness -> %d", v);
}

// Button events (called from buttons_tick() in the main loop context, so it's
// safe to touch settings/NVS here).
static void on_button(button_event_t ev)
{
    switch (ev) {
    case BTN_BRIGHT_UP:    nudge_brightness(+BRIGHT_STEP); break;
    case BTN_BRIGHT_DOWN:  nudge_brightness(-BRIGHT_STEP); break;
    case BTN_SHOW_TEMP:
        s_force_temp_until = (esp_timer_get_time() / 1000) + SHOW_TEMP_MS;
        ESP_LOGI(TAG, "show temp now");
        break;
    case BTN_ANTIPOISON:   antipoison_trigger(); break;
    case BTN_SHOW_IP:
        if (capture_ip(s_ip_octet)) {
            // 4 octets, each gets IP_OCTET_MS (+ a short gap between).
            s_show_ip_until = (esp_timer_get_time() / 1000) + 4 * IP_OCTET_MS;
            ESP_LOGI(TAG, "show IP %u.%u.%u.%u", s_ip_octet[0], s_ip_octet[1],
                     s_ip_octet[2], s_ip_octet[3]);
        } else {
            ESP_LOGW(TAG, "show IP: no address yet");
        }
        break;
    case BTN_ALARM_TOGGLE: {
        clock_settings_t c;
        settings_get(&c);
        c.alarm_enabled = !c.alarm_enabled;
        settings_set(&c);   // bumps version -> MQTT echoes; colon cue updates
        ESP_LOGI(TAG, "alarm %s (button combo)", c.alarm_enabled ? "ON" : "OFF");
        s_confirm_until = (esp_timer_get_time() / 1000) + CONFIRM_MS;
        break;
    }
    case BTN_PROVISION:
        // Set the one-shot flag and reboot into the SoftAP portal.
        provision_request_reboot();
        break;
    case BTN_FACTORY_RESET:
        netcfg_factory_reset();   // erases NVS + reboots (does not return)
        break;
    case BTN_SNOOZE_SHORT:
        alarm_snooze();
        break;
    case BTN_SNOOZE_LONG:
        if (alarm_dismiss())   // confirm the dismiss with a brief double-blink
            s_confirm_until = (esp_timer_get_time() / 1000) + CONFIRM_MS;
        break;
    }
}

void app_main(void)
{
    ESP_LOGI(TAG, "NixieClock starting (settings + RTC + SNTP + MQTT + temps)");

    nixie_init();

    // Settings first: it also performs the one-time nvs_flash_init that WiFi
    // depends on, and gives us the initial brightness/anti-poison config.
    settings_init();

    // Provisioning gate: if requested (one-shot flag, boot-held provision
    // button, or no creds at all), bring up the SoftAP portal instead of the
    // normal clock network stack. provision_run() blocks and reboots on save.
    if (provision_requested()) {
        uint8_t mac[6];
        char suffix[8];
        esp_read_mac(mac, ESP_MAC_WIFI_STA);
        snprintf(suffix, sizeof(suffix), "%02x%02x%02x", mac[3], mac[4], mac[5]);
        provision_run(suffix);
    }

    clock_settings_t cfg;
    settings_get(&cfg);
    uint32_t cfg_ver = settings_version();

    temps_init();
    temps_apply_settings(&cfg);
    temps_start();

    // TZ must be set before we interpret any RTC/SNTP time as local. netclock
    // also sets it, but do it here too so the boot-time RTC seed is correct.
    setenv("TZ", "CET-1CEST,M3.5.0,M10.5.0/3", 1);
    tzset();

    i2cbus_scan();   // log every I2C device so a new/unknown chip is easy to spot
    bool have_rtc = (rtc_open() == ESP_OK);
    if (have_rtc)
        seed_system_clock_from_rtc();
    else
        ESP_LOGW(TAG, "RTC not responding; running on SNTP/system time only");

    netclock_start();
    mqttctrl_start();
    webui_start();
    antipoison_init();
    apply_antipoison(&cfg);
    buttons_init(on_button);
    buzzer_init();
    alarm_init();

    uint32_t tick = 0;
    uint8_t anim = 0;
    int64_t last_anim_ms = 0;
    int last_level = -1;     // last brightness pushed to the driver

    for (;;) {
        int64_t now_ms = esp_timer_get_time() / 1000;

        buttons_tick(now_ms);   // debounce + dispatch via on_button()

        // Pick up settings changes (web UI / MQTT / buttons) cheaply.
        if (settings_version() != cfg_ver) {
            settings_get(&cfg);
            cfg_ver = settings_version();
            apply_antipoison(&cfg);
            temps_apply_settings(&cfg);
            last_level = -1;             // force a re-apply of brightness
        }

        time_t now = time(NULL);
        struct tm lt;
        localtime_r(&now, &lt);
        bool valid = (lt.tm_year + 1900) >= MIN_VALID_YEAR;
        int mins = lt.tm_hour * 60 + lt.tm_min;

        // Run the alarm state machine; it may start/stop the buzzer.
        if (valid) alarm_tick(&lt, &cfg, now_ms);
        bool ringing = valid && alarm_is_ringing();

        // Anti-poison only makes sense once we're showing a steady clock (the
        // slot-machine already exercises every cathode). A ringing alarm takes
        // priority over a scrub. When anti-poison runs it owns the display and
        // its own brightness, so skip the normal draw.
        if (valid && !ringing && antipoison_tick(now_ms)) {
            // routine drew this frame; it restores brightness when it ends
            last_level = -1;
        } else {
            // Apply effective brightness (manual / night / future sensor).
            int level = valid
                ? settings_effective_brightness(&cfg, mins, NO_SENSOR)
                : cfg.brightness;
            if (level != last_level) {
                nixie_set_brightness((uint8_t)level);
                last_level = level;
            }

            if (ringing) {
                // Flash the current time on/off (~1.6 Hz) while the alarm sounds.
                if ((now_ms / 300) % 2 == 0) show_time(&lt, cfg.h24);
                else                          show_blank();
                nixie_set_colon((now_ms / 300) % 2 == 0);
                vTaskDelay(pdMS_TO_TICKS(LOOP_MS));
                continue;
            }

            // IP readout (provision button short tap): walk the 4 octets, each
            // for IP_OCTET_MS with a short blank gap so equal/adjacent octets
            // are visually distinct.
            if (now_ms < s_show_ip_until) {
                int64_t elapsed = (4 * IP_OCTET_MS) - (s_show_ip_until - now_ms);
                int idx = (int)(elapsed / IP_OCTET_MS);
                if (idx < 0) idx = 0;
                if (idx > 3) idx = 3;
                bool gap = (elapsed % IP_OCTET_MS) >= (IP_OCTET_MS - IP_GAP_MS);
                if (gap) show_blank(); else show_octet(s_ip_octet[idx]);
                nixie_set_colon(false);
                vTaskDelay(pdMS_TO_TICKS(LOOP_MS));
                continue;
            }

            // Temperature: either the scheduled interlude near the end of each
            // minute, or a button-forced window (SHOW_TEMP). In the forced
            // window we show slot 0 for the first half, slot 1 for the second.
            bool drew_temp = false;
            if (valid && cfg.temp_enabled) {
                int slot;
                if (now_ms < s_force_temp_until) {
                    int64_t left = s_force_temp_until - now_ms;
                    slot = (left > SHOW_TEMP_MS / 2) ? 0 : 1;
                } else {
                    slot = temp_slot_for_second(lt.tm_sec);
                }
                int16_t centi;
                if (slot >= 0 && temps_get(slot, &centi)) {
                    show_temp(centi, cfg.temp_decimals, now_ms);  // drives colon itself
                    drew_temp = true;
                }
            }

            if (!drew_temp) {
                if (valid) {
                    // Dismiss-confirm: blink the whole display ~2x.
                    bool confirm = now_ms < s_confirm_until;
                    bool on = !confirm || ((now_ms / 250) % 2 == 0);
                    if (on) show_time(&lt, cfg.h24);
                    else    show_blank();

                    // Colon cue tied to whether the alarm feature is ENABLED (not
                    // whether it's still pending today) so it stays consistent
                    // through the dismissed "off for 23h59m" window:
                    //   snoozed  -> double pip   (distinct: "snoozed, will re-ring")
                    //   enabled  -> single pip   ("alarm on")
                    //   disabled -> normal blink / steady per blink_colon.
                    int  ph = now_ms % 1000;
                    bool colon;
                    if (!on)                       colon = false;
                    else if (alarm_is_snoozed())   colon = (ph < 150) || (ph >= 300 && ph < 450);
                    else if (cfg.alarm_enabled)    colon = (ph < 150);
                    else                           colon = cfg.blink_colon ? ((now_ms / 500) % 2 == 0) : true;
                    nixie_set_colon(colon);
                } else {
                    if (now_ms - last_anim_ms >= 100) {     // ~10 steps/sec
                        last_anim_ms = now_ms;
                        show_slot_machine(anim++);
                    }
                    nixie_set_colon(false);
                }
            }
        }

        if (++tick % 200 == 0)
            ESP_LOGI(TAG, "valid=%d synced=%d rtc=%d mqtt=%d night=%d lvl=%d",
                     valid, netclock_synced(), have_rtc, mqttctrl_connected(),
                     settings_is_night(&cfg, mins), last_level);

        vTaskDelay(pdMS_TO_TICKS(LOOP_MS));
    }
}

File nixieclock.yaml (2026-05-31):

esphome:
  name: nixieclock
  friendly_name: NixieClock
  on_boot:
    priority: -10
    then:
      # grab RTC time so the clock works offline
      - ds1307.read_time: rtc_time
      # enable clock & colon
      - lambda: |-
          id(clock_on) = true;
      - switch.template.publish:
          id: clock_display_sw
          state: true
      - switch.turn_on: colon_switch
      # keep Wi‑Fi disabled until user asks
      - wifi.disable

esp32:
  board: esp32dev
  framework:
    type: esp-idf

logger:
  level: NONE          # cut the driver spam

api:
  encryption:
    key: !secret nixieclock_api_key
  on_client_connected:
    then:
      - logger.log: "API client connected – syncing DS1307 from Home Assistant"
      - ds1307.write_time:
          id: rtc_time
      - logger.log: "DS1307 RTC updated successfully"

ota:
  - platform: esphome
    password: !secret nixieclock_ota_password

wifi:
  enable_on_boot: false
  ssid: !secret wifi_ssid
  password: !secret wifi_password
  min_auth_mode: WPA2


status_led:
  pin: GPIO04

# ---------------- TIME SOURCES ----------------
time:
  - platform: ds1307          # hardware RTC
    id: rtc_time
    address: 0x68
    update_interval: never    # we read manually at boot
  - platform: homeassistant   # for occasional re‑sync
    id: ha_time

globals:
  - id: dwell_ticks
    type: uint8_t
    initial_value: '59'      # 1 interval tick = 1 ms  
  - id: nixie_digits
    type: uint8_t[6]
    initial_value: '{10,10,10,10,10,10}'   # 10 = blank
  - id: btn_states
    type: bool[6]
    initial_value: '{false,false,false,false,false,false}'
  - id: hv_dots
    type: bool[6]
    initial_value: '{false,false,false,false,false,false}'
  - id: clock_on
    type: bool
    initial_value: 'true'
  - id: burn_active
    type: bool
    initial_value: 'false'

# === Outputs ===
output:
  # Anodes (74HC42)
  - platform: gpio
    id: an_b0
    pin: GPIO16
  - platform: gpio
    id: an_b1
    pin: GPIO17
  - platform: gpio
    id: an_b2
    pin: GPIO18

  # Cathodes (74141 BCD)
  - platform: gpio
    id: cat_b0
    pin: GPIO23
  - platform: gpio
    id: cat_b1
    pin: GPIO25
  - platform: gpio
    id: cat_b2
    pin: GPIO26
  - platform: gpio
    id: cat_b3
    pin: GPIO27

  # HV dot line (multiplexed)
  - platform: gpio
    id: hv_dot_line
    pin: GPIO32

  # RTTTL speaker
  - platform: ledc
    id: rtttl_out
    pin: GPIO19

# RTTTL player
rtttl:
  id: rtttl_player
  output: rtttl_out

# === Inputs ===
# ---------------- INPUTS ----------------
binary_sensor:
  - platform: gpio          # raw multiplexed
    id: btn_in_raw
    internal: true
    pin:
      number: GPIO14
      mode:
        input: true
        pullup: true

  # back buttons 1‑5 (templates)
  - platform: template
    id: back_btn_1
    name: "Back Button 1"
    lambda: 'return id(btn_states)[1];'
  - platform: template
    id: back_btn_2
    name: "Back Button 2"
    lambda: 'return id(btn_states)[2];'
  - platform: template
    id: back_btn_3
    name: "Back Button 3"
    lambda: 'return id(btn_states)[3];'
  - platform: template
    id: back_btn_4
    name: "Back Button 4"
    lambda: 'return id(btn_states)[4];'

  # Back Button 5 turns Wi‑Fi on for this session
  - platform: template
    id: back_btn_5
    name: "Back Button 5"
    lambda: 'return id(btn_states)[5];'
    on_press:
      - logger.log: "Back Button 5 pressed – enabling Wi‑Fi"
      - wifi.enable

  # Snooze (GPIO15)
  - platform: gpio
    id: snooze_btn
    name: "Snooze Button"
    pin:
      number: GPIO15
      mode:
        input: true
        pullup: true
      inverted: true

# === Sensors ===
sensor:
  - platform: adc
    id: batt_raw
    name: "Battery Voltage"
    pin: GPIO34
    attenuation: 12db
    update_interval: 30s
    samples: 10
    accuracy_decimals: 2
    filters:
      - multiply: 2.0   # 22k/22k divider
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

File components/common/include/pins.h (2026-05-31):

// Central pin map for the NixieClock (UCB32 controller + Unidisp display board).
//
// The display is a 6-tube, time-multiplexed nixie panel. One tube is lit at a
// time; the firmware walks through them fast enough to look continuous.
//
//   Tube select (74x42, "S0..S2" on the Unidisp X2 header):
//     code 0 = RIGHTMOST tube ... code 5 = LEFTMOST tube, code 6/7 = display off.
//   Digit value (MH74141, "D0..D3"): BCD. A value >= 10 (e.g. 0xF) blanks the
//     selected tube without disabling its anode — handy for per-tube dimming
//     while still reading that tube's multiplexed button.
//
// All Unidisp logic is 5V TTL but reads the ESP32's 3.3V output as logic high.
// KEY is open-drain active-low and idles high through the ESP's internal pullup.
#pragma once

#include "driver/gpio.h"

// --- Tube select (anode multiplex, 74x42 address) ---
#define PIN_SEL0        GPIO_NUM_16   // S0 / LSB
#define PIN_SEL1        GPIO_NUM_17   // S1
#define PIN_SEL2        GPIO_NUM_18   // S2 / MSB

// --- Digit value (cathode, MH74141 BCD) ---
#define PIN_BCD0        GPIO_NUM_23   // D0 / LSB
#define PIN_BCD1        GPIO_NUM_25   // D1
#define PIN_BCD2        GPIO_NUM_26   // D2
#define PIN_BCD3        GPIO_NUM_27   // D3 / MSB

// --- Decorations ---
#define PIN_DOT         GPIO_NUM_32   // DP: per-tube decimal points (multiplexed, H = on)
#define PIN_COLON       GPIO_NUM_33   // COL: the ':' separator LEDs (not multiplexed)

// --- Inputs ---
#define PIN_KEY         GPIO_NUM_14   // multiplexed front buttons, active-low, needs pullup
#define PIN_SNOOZE      GPIO_NUM_15   // snooze button, active-low

// --- Audio ---
#define PIN_BUZZER      GPIO_NUM_19   // ALM: passive piezo, driven via LEDC

// --- I2C bus (DS3231 RTC @ 0x68; future BH1750 light sensor @ 0x23) ---
#define PIN_I2C_SDA     GPIO_NUM_21
#define PIN_I2C_SCL     GPIO_NUM_22

// --- 1-Wire (DS18B20 temperature, RMT-driven) ---
#define PIN_ONEWIRE     GPIO_NUM_13   // needs a 4.7k pull-up to 3.3V on the data line

// --- Misc ---
#define PIN_STATUS_LED  GPIO_NUM_4
#define PIN_BATT_ADC    GPIO_NUM_34   // ADC1_CH6, 22k/22k divider (x2). Unused in v1.

#define NIXIE_NUM_TUBES 6

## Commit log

2026-05-31 Initial commit: ESP-IDF nixie clock firmware
    Complete rewrite of the nixie clock from ESPHome to ESP-IDF + PlatformIO.
    Display: GPTimer-driven multiplex with firmware PWM brightness (ghost-free),
    night dimming, anti-cathode-poisoning, cold-start animation.
    Time: SNTP + PCF8563/DS1307/DS3231 RTC (auto-detect), Europe/Prague.
    Temperature: 2 slots fed by MQTT or DS18B20 (RMT 1-Wire), colon-as-decimal,
    negative-blink, configurable decimals.
    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
    [BOM.csv, UCB32-EdgeCuts.dxf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]
2026-05-31 Add factory-reset button to HA and web UI
    Centralize the NVS-wipe-and-reboot in netcfg_factory_reset() (was inline in the
    button handler). Expose it as:
    - an HA button (payload_press "RESET", config/restart entity) so a stray or
    retained empty message can't trigger it;
    - a web UI button behind a JS confirm() that POSTs the same RESET token.
    Both require the exact token firmware-side before wiping.
    [main.c]
2026-05-31 Factory reset: force SoftAP setup instead of silently reconnecting
    nvs_flash_erase() wiped stored creds, but secrets.h is still compiled in as a
    fallback, so the device just reconnected to that network on reboot (settings
    reset, but not the network — confusing for a "factory reset"). After the wipe,
    re-init NVS and set the one-shot provreq flag so the next boot enters SoftAP
    provisioning regardless of the secrets.h fallback.
2026-05-31 netcfg: trust NVS once provisioned; idle MQTT with no broker
    The per-field secrets.h fallback meant a factory-reset clock that was
    re-provisioned with WiFi only would still pull the compiled-in MQTT broker and
    reconnect to it. Fix the policy: secrets.h is a first-boot convenience only —
    if a WiFi SSID is stored (device provisioned), NVS is authoritative and an
    empty key means empty (blank MQTT host = no MQTT).
    mqttctrl now treats an empty broker host as "idle": it builds the client but
    doesn't start it (no spinning on mqtt://:1883), and reconnect() starts/stops it
    as the host is set/cleared.
2026-05-31 Add CLAUDE.md working notes
    Session-continuity notes for future work: build/flash workflow (no auto-reset,
    stale-cache rebuild), the control-core architecture and how to add a setting,
    naming/credential gotchas, hardware quick-ref, and current state.
2026-05-31 DS sensors: live web list with assign/unassign, per-sensor HA entities
    Poll every discovered DS18B20 (not just slot-assigned ones) and cache each
    reading, so a sensor that only feeds Home Assistant still has a live value.
    - temps: temps_list_ds() returns each sensor's ROM + temp + freshness;
    slots now read from the shared cache instead of doing their own conversion.
    - webui: replace the manual ROM paste fields + static "Found sensors" line
    with a live list showing each sensor's temperature and assign/unassign
    buttons (assign also flips the slot source to ds18b20).
    - mqttctrl: state payload carries a per-ROM "ds" object; publish one HA
    temperature entity per sensor, (re)published on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
2026-06-06 Alarm: status (snoozed / off-until-next) on web+HA, melody preview, colon-cue fix
    State surfaces now report a human-readable alarm status string ("disabled" / "ringing" / "snoozed 6m" / "off 23h59m" / "armed 7h12m"), computed in the alarm component (honours the day-of-week mask when working out the time to the next occurrence). Exposed via control_state_json (web/REST) and the MQTT state payload + a new HA "Alarm status" sensor.
    Add a melody preview: alarm_preview_melody() plays the configured melody once (non-looping). Wired as the "alarm_test" action over REST and MQTT, with a Play button in the web UI and a "Test melody" button in HA.
    Fix the colon cue: it keyed off alarm_is_armed() (fa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
    [main.c]
2026-06-06 Stop tracking KiCad lock/autosave files; gitignore them
    Untrack the .lck locks, _autosave schematic, and #auto_saved_files# (KiCad
    regenerates these). Project files and the backup zips stay tracked. Add the
    matching .gitignore patterns so they don't creep back in.
2026-06-06 Add licenses: GPLv3 (firmware) + CERN-OHL-S v2 (UCB32 board)
    Firmware/code under GNU GPL v3 (root LICENSE). The UCB32 controller board
    (PCB_Sources/ucb vibecheck_final/) under CERN-OHL-S v2 (strongly reciprocal),
    scoped to that folder so it doesn't overreach onto the third-party Unidisp
    display board, which keeps its own CERN-OHL-W license. README gains a License
    section spelling this out.
2026-06-06 README: credit @Unipuls80 (Unidisp) and link upstream boards
2026-06-06 Add 3D-printed enclosure files (renamed) + print/assembly notes
    Rename the Czech-named .3mf parts to clear English names, add a 3D_Files/README
    with a parts table (qty, supports, material, scaling) and the M3 insert/screw
    hardware for the rear panel. Link it from the main README.
    [component-panel.3mf, foot-tpu.3mf, front-bezel.3mf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]
2026-06-06 3D files: PETG/qty fixes, add auto-generated render previews
    Correct the notes (snooze cap is one rocker over two switches; everything
    rigid is PETG, picked for the hot 7805). Add isometric PNG renders of every
    part in renders/ plus the _render.py helper, and embed them as previews in the
    parts table.
2026-07-28 Add dual-OTA partitions + web firmware upload
    Repartition 4MB flash from a single factory app to a dual-OTA layout
    (otadata + two ~1.875MB ota_0/ota_1 slots + 128KB spiffs), keeping nvs and
    phy_init byte-for-byte so settings and WiFi/MQTT credentials survive the
    one-time serial reflash. App uses ~55% of a slot, leaving headroom for a
    future NimBLE build.
    webui: add POST /api/ota streaming handler (esp_ota_begin/write/end/
    set_boot_partition + reboot) and a Firmware section with file upload,
    progress, and a running version+slot readout. control_state_json now emits
    a "fw" field (version @ active ota slot). Docs updated in README, GUIDE
    (EN+CZ), and CLAUDE.md.
    Verified end-to-end on hardware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
2026-07-28 Blank tubes during OTA + web log viewer
    nixie: add nixie_hold_off() — a latched, ISR-checked blank that forces all
    tubes + colon dark regardless of framebuffer/brightness. The OTA handler
    asserts it for the whole flash so the multiplexed display no longer glitches
    while esp_ota_write stalls the CPU/cache; it's cleared only on OTA failure
    (success reboots).
    weblog: new component that hooks esp_log_set_vprintf into a 6KB RAM ring
    buffer (chaining to the previous console sink). Exposed over the web UI via
    GET /api/log and a Logs panel with optional auto-refresh — the assembled
    clock has no serial access, so this is the way to read device logs.
    Initialised first in app_main so boot logs are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
2026-07-28 Harden OTA against a stalled upload
    The recv loop treated every socket timeout as 'retry forever', so a
    dropped Wi-Fi upload mid-stream left the single httpd worker spinning with
    the display latched blank — the whole device looked hung and needed a power
    cycle. Bound consecutive recv timeouts (~30s total via recv_wait_timeout)
    and, on exceed, abort the OTA, un-blank the tubes, and return 408 so the
    device stays responsive on the current firmware.
    Claude-Session: https://claude.ai/code/session_011ikGCnoGzYX8Vj2KBX8jTZ
2026-07-28 nixie: cut anode on blank tubes to kill faint glow
    A blank tube kept its anode strobed (only the cathode was de-selected via
    BCD_BLANK) so the multiplexed button in that slot could still be scanned. Over
    imperfectly-blanked cathodes that leaks a faint glow — visible as dim ghosts
    on e.g. the leading (blank) temperature digits. Now a blank tube parks its
    anode at SELECT_OFF too whenever the display is on, so it's truly dark; its
    key scan is skipped while dark (only leading zeros / the temp interlude are
    blank-while-lit, and none are button tubes during the normal time display).
    Whole-display-off (brightness 0) still selects tubes so bright+ can recover,
    and the OTA hold now parks anodes ful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
2026-07-28 Add Shelly BLU H&T temperature over BLE (BTHome v2)
    New 'blescan' component: NimBLE passive observer scan decoding BTHome v2
    advertisements (adapted from MAX7219_Display/src/bthome.cpp into C). A device
    assigned to a temp slot (source TEMP_SRC_SHELLY, matched by MAC) feeds it via
    temps_set_shelly(); a registry backs the web picker. Unencrypted BTHome only.
    Wiring: settings gains shelly_mac[TEMP_SLOTS][6] + TEMP_SRC_SHELLY
    (SETTINGS_VERSION 2->3); control handles temp{N}_mac + 'shelly' source and
    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
2026-07-28 Shelly low-battery indicator; stop MQTT time spam
    Low battery: blescan feeds the sensor's BTHome battery % into the temp
    slot (temps_battery/temps_set_shelly_battery). It surfaces in /api/state, the
    web UI (next to the slot value + a warning in the picker), and Home Assistant
    (a per-slot battery sensor). On the tubes, a slot whose Shelly sensor is
    <=20%% blinks just the colon during that reading — deliberately distinct from
    the whole-reading blink reserved for negative temperatures.
    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
2026-07-28 Docs: refresh README/GUIDE/CLAUDE for OTA, web log, Shelly BLE + battery
    New REST endpoints (ota/log/blescan), OTA + web-log features, Shelly BLU
    button-to-identify + low-battery colon cue across README/GUIDE (EN+CZ), and the
    blescan/colon-cue working notes in CLAUDE.md.
    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
2026-07-28 temps: per-slot calibration offset
    Add temp_offset[TEMP_SLOTS] to settings (v3->v4); applied in temps_get on read-out so it shifts the tubes + MQTT/REST state alike, while the raw DS picker list stays uncalibrated. Exposed as temp{N}_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
2026-07-28 Night dimming: fixed / sunrise-sunset / BH1750 lux modes
    night_mode setting (default sun) resolved in settings_brightness_for(): fixed clock-time window, on-device NOAA sunrise/sunset (offline, from lat/lon), or ambient lux from an optional BH1750 auto-probed at I2C 0x23/0x5C at boot. UI/HA offer the lux mode only when the sensor is present. Schema v4->v5 (lat_e2/lon_e2/night_mode). Sun helpers take int64_t epoch to keep <time.h> out of the widely-included settings.h (it collided with blescan's dev_t).
    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
2026-07-28 Configurable interludes + date, REST GET, phone time-set, OTA colon blink
    Schema v5->v6: per-interlude start-second/length (temp1/temp2) + a new date interlude (DOW _ DD:MM), settable POSIX tz. REST GET aliases for /api/set and /api/action; /api/settime (web + SoftAP porta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
2026-10-17 Fix time handling: RTC holds UTC, alarm/antipoison cross-task races, 64-bit BLE timestamps
    RTC: the chip used to hold local time, so an offline power cycle after a DST change (or a TZ edit) booted the clock an hour off. It now holds UTC via rtc_get_epoch/rtc_set_epoch; legacy contents are detected by an NVS marker (rtc_utc), read once as local time and rewritten as UTC. Factory reset keeps the marker.
    Alarm: snooze/dismiss from the web UI or MQTT raced the main-loop tick, which could restart the buzzer while the state became SNOOZED. State transitions now take a mutex; alarm_init runs before the network surfaces start. antipoison_trigger now only raises a request flag consumed by antipoison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
2026-10-22 Add optional Shelly BLE time sync (sync-now button + daily, yields to NTP)
    New shellytime component: blescan feeds every manufacturer AD; Gen2+ Shelly gateways broadcast a time beacon (company 0x0BA9, block 0x0D: unix, std offset, DST window). A sync takes the median of fresh senders, each stamp plus time since first heard (removes the 0..3 s burst lag), and sets system clock + RTC + persisted epoch. TZ is untouched.
    shelly_sync action (web/REST/MQTT, HA button) raises a flag the main loop applies. shelly_time_daily (HA switch) syncs ~1 min after boot then every 24 h, skipped while SNTP synced within 24 h (netclock_last_sync_ms). Stored in the reserved bright_min byte: no schema bump. Web C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
2026-10-22 Fix web UI lockout from idle browser sockets (lwIP sockets 10 -> 16)
    lwIP's default 10 sockets ran out before httpd's 7-session cap (httpd keeps 3 internal, plus MQTT/SNTP), so ~6 idle keep-alive sockets from two open browser tabs made the server accept-and-drop every new client until the browser released them, minutes later. Reproduced: 6 held idle connections -> fresh request fails. With 16 sockets httpd hits max_open_sockets first and its LRU purge evicts the oldest idle client. The Shelly time panel now polls every 10 s instead of 3 s.
2026-10-22 Tunable anti-poison: interval, length, speed, 5 animations + mix, pause for interludes
    Settings v7 appends ap_step_ms/ap_anim/ap_pause_ild; a v6 blob is migrated in place (copied over defaults, new tail re-defaulted) instead of being reset. New control keys ap_period (min), ap_duration (s), ap_speed (ms/step), ap_anim, ap_pause, plus ap_status in the state JSON. Animations: cascade (original), sync, random, reels, wave, mix (round-robin per run). With ap_pause, a due automatic scrub only starts where ceil(duration)+1 s fit outside the temp/date windows (longest gap as fallback, so at most a minute's wait); manual Scrub always runs. Web fields, HA numbers/select/switch, GUIDE EN/CZ, README, C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
